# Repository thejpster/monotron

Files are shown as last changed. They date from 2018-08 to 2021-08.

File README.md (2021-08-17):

# Monotron.

> A simple 1980's home computer style application for the Tiva-C Launchpad

## The Monotron is no more

Monotron was fun, but it was only ever a tech demo rather than something we could build on. Check out <https://github.com/neotron-compute/> for our new family of ARM-based, Rust-powered home computers. 

## Introduction

Monotron is powered by a Texas Instruments TM4C123 microcontroller, containing
an ARM Cortex-M4 core and a number of peripherals. This processor was chosen
because it is available on an inexpensive dev-kit - the Tiva-C Launchpad - and
I happened to have some lying around. The challenge I set myself was, how much
can you squeeze out of this tiny CPU? And can you do it all in pure-Rust?

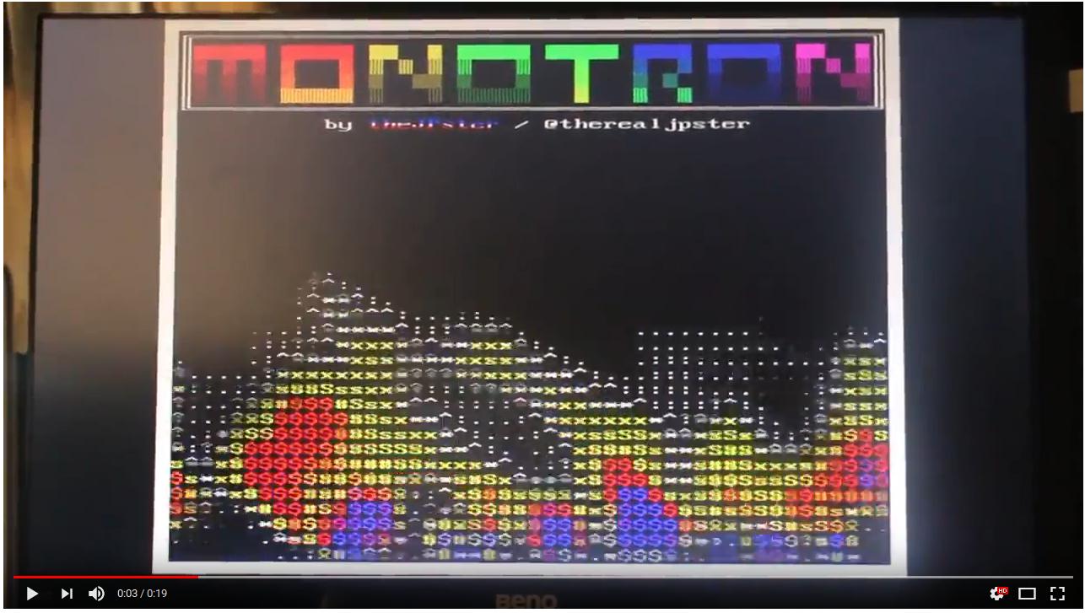
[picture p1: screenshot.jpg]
YouTube screenshot of a video of Monotron Monotron on Youtube

[See Monotron in Action!](https://www.youtube.com/watch?v=7x_92PXKSN4)

## The Future

Monotron has been replaced by the [Neotron 32](https://github.com/neotron-compute/Neotron-32-Hardware), part of the [Neotron family](https://neotron-compute.github.io). All future work will happen under the Neotron banner, and this repo is in archive mode.

## Features

* 800x600 8-colour VGA output
* 32 KiB SRAM (24 KiB usable for applications)
* 256 KiB Flash ROM
* Choice of low-memory 48x36 text display mode or full 384x288 bitmap graphics mode
* 8-bit mono audio output with 3 channel, 4 waveform synthesiser
* USB Serial I/O
* Atari 9-pin joystick interface
* Simple command-line interface
* I2C expansion interface
* Loadable apps
* Battery backed real-time clock*
* 25-pin IBM PC style parallel printer port*
* MIDI In, Out and Through*
* PS/2 Keyboard and Mouse*
* RS-232 Serial port*
* Watch this space!

 _* Requires additional hardware, included on the [Monotron PCB](#monotron-pcb)_

## Video

Monotron generates an 800x600 VGA video signal at 60 Hz using three SPI
peripherals and a timer to generate the horizontal sync signals. It can do
this because the VGA signal has a pixel clock of 40 MHz and the Tiva-C
Launchpad's TM4C123 CPU runs at 80 MHz. We save on the number of pixels we
have to push through the SPIs by running at half-resolution horizontally
(giving 400x600), which also halves the pixel clock to 20 MHz. I did try 40
MHz mode and it didn't work.

Monotron has two 'modes' it can display on this VGA output.

### Text Mode

Text Mode has a 48 character by 36 line display. Each character cell is 8
pixels wide and 16 pixels high and can take any character from the 8-bit [MS-
DOS Code Page 850](https://en.wikipedia.org/wiki/Code_page_850) character set,
and can have any foreground and background colour from the supported set:

* White
* Red
* Yellow
* Green
* Cyan
* Blue
* Magenta
* Black

The text buffer takes up `48 x 36 x 2 = 3,456` bytes of SRAM.

The built-in font is taken from
[FreeBSD](http://web.mit.edu/freebsd/head/share/syscons/fonts/cp850-8x16.fnt).
There's also a second font which implements Teletext block graphics (or
'sixels').

Any line of text can be displayed in "double height" mode, showing either the
top-half or bottom-half.

Finally, the display is framed with an 8 pixel border at the sides and a 12
pixel border at the top and bottom, to make everything fit neatly and to help
with any minor overscan issues if you use an actual CRT monitor.

### Graphics Mode

Graphics Mode can be enabled and disabled at run-time. It's not enabled by
default because bitmap graphics take up a lot of RAM!

You can attach a 1-bit-per-pixel graphics buffer that is some multiple of 384
pixels (i.e. 384 bits or 48 bytes) long. This buffer is displayed using line-
doubling (i.e. every line is shown twice) so you can go up to 384x288
resolution maximum, which will fill the screen. Each bit from the bitmap is
coloured according to the text cell (see above) it sits on top of, much like a
ZX Spectrum. A full-screen bitmap therefore uses the 3,456 bytes of SRAM from
text-mode plus an additional `384x288 / 8 = 13,824` bytes of SRAM.

## Compiling

You will need to build using Rust Nightly, as we need various experimental
features for Embedded development that are not yet available in Stable.

```
$ rustup toolchain install nightly
$ git clone https://github.com/thejpster/monotron.git
$ cd monotron
$ rustup override set nightly
$ rustup target add thumbv7em-none-eabihf
$ cargo build --release
```

To program the board, you can use lm4flash:

```
$ cargo build --release
$ arm-none-eabi-objcopy -O binary ./target/thumbv7em-none-eabihf/release/monotron ./target/thumbv7em-none-eabihf/release/monotron.bin
$ lm4flash ./target/thumbv7em-none-eabihf/release/monotron.bin
```

Or you can debug in GDB (which will automatically load the program first):

```
$ openocd
<switch to a different terminal>
$ cargo run --release
```

OpenOCD should read our `openocd.cfg` file, which directs it to use the
correct configuration. You may need to run `sudo openocd` if your user doesn't
have permission to open the USB device.

To exit GDB, you may need to press Ctrl-C multiple
times, as it seems it can get a bit stuck.

## Connecting

You have two options when running a Monotron.

1. You can take a bare Tiva-C Launchpad and wire up various connectors using
   the pin-outs in the following sections.
2. You can skip all that make yourself a [Monotron PCB](#monotron-pcb)!

### VGA

Your VGA connector requires five wires:

* Pin 1: Red - connect to PF1 via a 330 Ohm resistor.
* Pin 2: Green - connect to PB7 via a 330 Ohm resistor.
* Pin 3: Blue - connect to PD3 via a 330 Ohm resistor.
* Pin 5: Ground - connect to GND
* Pin 6: Red Return - connect to GND
* Pin 7: Green Return - connect to GND
* Pin 8: Blue Return - connect to GND
* Pin 13: H-Sync - connect to PB4
* Pin 14: V-Sync - connect to PB5

I'm using this arrangement using random resistors I found on my desk, and it
works for me (although the picture is a bit dim, as it actually produces about
0.6V peak rather than 0.7V):

```
-----+
     |     +------+ 330 Ohm        Co-ax in the VGA cable
PB7 o+-----|      |------------(o)==================)+
     |     +------+                                  |
-----+                                               |
                                                    +-+
                                                    | |
                                                    | | 75 Ohm
                                                    | | (in Monitor)
                                                    +-+
                                                     |
                                                     o
                                                    GND
```

The 330 Ohm resistor forms a resistive divider with the 75 Ohm resistor in the
monitor. This is needed to drop the 3.3V output down to 0.7V. Some monitors
are more tolerant of over voltage than others. The higher the resistor you
use, the less current you pulling out of the GPIO pin (we're just over 8mA
currently, which is a bit high) but the lower the voltage the monitor will see
and the dimmer your picture will be. Conversely if you lower the resistor,
more current will flow but it'll be a brigher picture. I'd save your chip from
damage and just wind the brightness control up!

Obviously only one channel is shown above - wire up the blue and red channels
in exactly the same fashion. Finally, don't forget to keep your wires short!
You will have noise if you try and send a 20 MHz signal down 10cm of
unshielded wire.

In a perfect world, your board would offer a 75 ohm source impendance matching
the monitor's 75 ohm impedance, to reduce reflections, but at this resolution
it doesn't seem to matter. If you want do do that, you'll need to make a
resistive divider to drop the 3.3V to 1.4V, and then feed that through a
high-bandwidth (>20 MHz) unity-gain amplifier, with a 75 ohm resistor on the
output. The pair of 75 ohm resistors will then drop the 1.4V to 0.7V in the
monitor.

### UART

Monotron primarily uses UART0, which is converted to USB Serial by the
on-board companion chip on the Tiva-C Launchpad. Connect with your favourite
Serial terminal at 115,200bps, then send UTF-8 characters and they'll get
converted to virtual keyboard input, allowing you to drive the Monotron.

There's also a second UART (UART1), which has RTS/CTS hardware handshaking
lines connected (but not DSR, DTR or RI). On the Monotron PCB these are
brought out to pin header J8. By fitting six jumpers on this header, the
on-board MAX3232 level shifter is activated, driving RS-232 signals on the
DE9M connector, J12. This connector is wired as [Data Terminal
Equipment](https://en.wikipedia.org/wiki/Data_terminal_equipment) or _DTE_ (as
opposed to [Data Communications
Equipment](https://en.wikipedia.org/wiki/Data_circuit-terminating_equipment)
or _DCE_). This means that Monotron transmits data on DE9 pin 3, and it's
designed to connect to Serial AT modems or other peripherals. Other computers
(like an old IBM PC) and even USB to RS-232 adaptors are most likely wired DTE
and so to connect one to the Monotron you'll most likely need a [null-modem
cable](https://en.wikipedia.org/wiki/Null_modem) (one that swaps pins 3 + 4
and pins 7 + 8).

Bonus points to the first person to write a BBS program for Monotron that lets
you dial up on a 56k modem.

Extra bonus points to the first person to write an xmodem file transfer
program so you can transfer files from SD card over RS-232 to an xmodem
utility on your old MS-DOS 3.3 IBM PC.

_Note: The Joystick connector looks the same as the RS232 connector - don't
mix them up!_

On the Monotron PCB, a third UART (UART3) is routed through various
opto-isolators to the MIDI In and MIDI Out ports. The MIDI Through port just
repeats everything received on the MIDI In port.

Finally, also on the Monotron PCB, a fourth UART (UART7) connects to a 5V
AtMega48 which is used as an I/O expander. This microcontroller drives two
PS/2 ports (one for keyboard, one for the mouse) as well as a full IBM
PC-style 25-pin parallel printer port.

| Launchpad Pin | Tiva-C Pin | External Pin | Function (from Monotron's point of view) |
|---|---|---|---|
| N/A | PA0 | N/A | USB Serial Rx |
| N/A | PA1 | N/A | USB Serial Tx |
| J4.8 | PD6 | J12 pin 3 | RS-232 Tx |
| J4.9 | PD7 | J12 pin 2 | RS-232 Rx |
| J4.10 | PF4 | J12 pin 7 | RS-232 RTS |
| J3.2 | GND | J12 pin 8 | RS-232 CTS |
| J4.6 | PC6 | J11 pin 4/5  | MIDI In |
| J4.7 | PC7 | J9 pin 4/5 | MIDI Out |
| N/A | N/A | J10 pin 4/5  | MIDI Through  |

### Audio

Monotron can generate 8-bit audio output using PWM on pin PE4. I use the
[monotron- synth](https://github.com/thejpster/monotron-synth) which has a
three-channel wavetable synthesiser which can bleep and bloop with square
waves, sine waves, sawtooth waves and generate white noise.

You'll need to run the pin through a low-pass filter to remove the noise, and
connect it to an amplifier as the GPIO pin won't really supply much current.

| Launchpad Pin | Tiva-C Pin | TRS | Function  |
|---|---|---|---|
| J1.5 | PE4 | Ring/Tip |Audio Left |
| J1.6 | PE5 | Tip |Audio Right|
| J3.2 | GND | Sleeve |Common |

Currently audio only comes out as Mono on PE4 (Left). If this is a problem for
your amplifier, setting jumper J1 on the PCB to 1-2 allows you to route Audio
Left to Sleeve as well as Tip. Setting J1 to 2-3 enables stereo support,
should that ever get developed.

### Joystick

There are five active-low inputs corresponding to Up, Down, Left, Right and
Fire. You can connect these inputs to a standard Atari or Commodore 9-pin
Joystick as follows:

| Launchpad Pin | Tiva-C Pin | Joystick Pin | Function |
|---|---|---|---|
| J3.8 | PE2 | 1 | Up |
| J3.9 | PE3 | 2 | Down |
| J4.8 | PD6 | 3 | Left |
| J4.9 | PD7 | 4 | Right |
| J4.10 | PF4 | 6 | Fire |
| J3.2 | GND | 8 | Ground |

A Sega Master System (tm) controller should work, except you'll only be able
to use Button 1 not Button 2. A Sega Mega Drive (tm) controller probably won't
work because it has more buttons than there are pins, and so uses a 5V powered
multiplexer to select between the two banks of buttons. 15-pin Analog PC
joysticks won't work either.

### SD Card

You can load programs and data from an SD card, from the first Primary MBR
(standard old-style MS-DOS) partition, formatted as either FAT16 or FAT32. Use
a standard SD Card SPI breakout adaptor, connected up as follows:

| Launchpad Pin | Tiva-C Pin | Function |
|---|---|---|
| J2.10 | PA2 | Clock |
| J2.9 | PA3 | Chip Select  |
| J2.8 | PA4 | MISO/Data Out|
| J1.8 | PA5 | MOSI/Data In |

SD cards operate at 3.3v so no level shifters are required, but many cards
will require a 47k (well, between 10k and 100k) pull-up to 3.3v on all four
data pins. If you don't use these pull-ups, the pins float while the Monotron
is booting, and these fluctuations may upset the SD card, giving you random
timeouts and other spurious effects. Some cards tolerate this better than
others, so YMMV. If in doubt, just add the pull-ups (they're missing on rev
0.7.0 of the PCB, but will be on 0.8.0+).

On the console you use the `mount` command to scan the disk, then `dir` to
show the root directory contents. You can also `dload`, `ddump` and `dpage`
commands to load, hex-dump and print files to the screen. A program loaded
with `dload` can subsequently be executed with the `run` command.

### I2C

The [Monotron PCB](#monotron-pcb) has an I2C expansion header connected to
`I2C1`. The PCB can also optionally be fitted with an [Microchip
MCP7940N](https://www.microchip.com/wwwproducts/en/MCP7940N) battery-backed
real time clock chip. Driver support for this chip is TBC.

The PCB pulls-up the I2C bus to 5V through 4.7k pull-ups. On these particular
pins the TM4C123 happens to be 5V tolerant and so it simply runs the I2C pins
in open-drain mode without a level shifter.

| Launchpad Pin | Tiva-C Pin | External Pin | Function |
|---|---|---|---|
| J2.1 | GND | J6 pin 1 | Ground |
| J3.1 | 5V | J6 pin 2 | 5V Power |
| J1.10 | PA7 | J6 pin 3 | SDA |
| J1.9 | PA6 | J6 pin 4 | SCL |

### PS/2 Keyboard

The initial PS/2 keyboard support sort of worked, but it wasn't reliable I so
took it out again. The fundamental problem was that it's really hard to sample
a 10 to 15 kHz incoming synchronous signal without using SPI slave peripheral
(they're all in use) and while bit-bashing timing-critical video signals at 20
MHz. Either you drop random key events (leading to missing characters or stuck
keys), or the video wobbles every time a key is pressed (like a ZX81). Neither
was ideal.

On the [Monotron PCB](#monotron-pcb) I work around this issue by adding an
Atmel AtMega48 microcontroller as an I/O expander, connected to [UART](#uart)
7. Look in the [`avr_kb`](./avr_kb) folder for more information.

__Note:__ There's a bug in the 0.7.0 PCB where both PS/2 connector pinouts are
mirror image, compared to how they should be. It happened because although the
connector drawings said "Bottom View" quite clearly, I didn't pay enough
attention and assumed they were viewed from above! To use the PS/2 connectors,
they must be fitted to the underside of the PCB (i.e. opposite to all the
other connectors). This will be fixed in the next PCB revision.

### MIDI

The [Monotron PCB](#monotron-pcb) has three 5-pin DIN MIDI ports: In, Out and
Through. These are connected to UART 3.

### Parallel Printer Port

The 25-pin Parallel Printer Port is connected to the Monotron PCB's AtMega48
I/O controller. You send commands to the AtMega to get it to drive the printer
port. Currently only SPP (classic mono-directional support as found on the
original IBM PC) is planned for support. Support for the fancier EPP and ECP
modes is TBD.

## Monotron PCB

There's now a PCB! It features:

* 2x20 pin headers, to mate with the TM4C123 Launchpad (other Launchpads like
  the TM4C129 and MSP430 have not been tested and almost certainly won't work)
* 5V power jack (2.1mm barrel jack, centre +ve)
* [VGA](#vga) port (DE15HD female)
* Atari/Commodore [joystick](#joystick) port (DE9 male)
* [Micro-SD Card](#sd-card) slot
* [3.5mm stereo line out](#audio)
* [RS-232](#uart) port (DE9 male)
* 2.54mm (100 mil) jumpers to disconnect the RS232 driver and allow you to
  connect a 3.3v FTDI type TTL serial cable instead.
* [MIDI](#midi) In, Out and Through ports, with opto-isolation (5-pin DIN)
* 4-pin 2.54mm pitch (100 mil) [I2C](#i2c) expansion header (GND, 5V, SDA, SCL)
* Microchip MCP7940N I2C Real-Time Clock with battery back-up
* AtMega48 microcontroller, controlling:
  * IBM PC style parallel printer port (DB25 female)
  * PS/2 Keyboard port (6-pin mini-DIN)
  * PS/2 Mouse port (6-pin mini-DIN)

See the [pcb](./pcb) folder for Kicad files, Gerbers and PDF Schematics. If
you want to buy a PCB (with or without a kit of parts) send a message to
@therealjpster on Twitter, or via my Github e-mail. Rev 0.7.0 has some rough
edges, but I'm working on it.

## Running

When running, a simple command driven interface is presented. Commands can be
entered over serial, or using a PS/2 keyboard. Commands are split on
whitespace and then interpreted based on the left-most word. Enter the command
'help' to see a list of commands. Some commands place you in to a sub-menu -
use 'exit' to return to the previous menu.

## Loading apps

Applications can be compiled and loaded into RAM for exection. They must be
linked to run from address `0x2000_2000` and take less than 24 KiB for all
code and data combined. See the table below:

| Address | Length  | Description  |
|---|---|---|
| 0x0000_0000 | 256 KiB | OS Code |
| 0x2000_0000 | 8 KiB | OS Data |
| 0x2000_2000 | 24 KiB  | Application  |

The first four bytes of the image must be the address of the start function,
with prototype `fn start(const struct callbacks_t* callbacks) -> int32`. Apart
from that, applications are free to apportion the remaining 24,572 bytes as
they see fit.

*Note:* The application does not need to provide a stack region - the Monotron
ROM will handle that using the system stack.

The callback structure supplied to the application's entry function is defined
in `api.rs`, but in C looks like:

```C
struct callbacks_t {
    int32_t (*putchar)(void* p_context, char ch);
    int32_t (*puts)(void* p_context, const char*);
    int32_t (*readc)(void* p_context);
    void (*wfvbi)(void* p_context);
    int32_t (*kbhit)(void* p_context);
    void (*move_cursor)(void* p_context, unsigned char row, unsigned char col);
    int32_t (*play)(void* p_context, uint32_t frequency, uint8_t channel, uint8_t waveform, uint8_t volume);
    void (*change_font)(void* p_context, uint32_t mode, const void* p_font);
    uint8_t (*get_joystick)(void* p_context);
    void (*set_cursor_visible)(void* p_context, uint8_t visible);
};
```

The C functions exported to the apps are:

* `puts` - print an 8-bit string (certain escape sequences are understood).
  Note that unlike the C routine of the same name, this function does not
  append a newline automatically. It is more like `fputs(s, stdout)`.
* `putchar` - print an 8-bit character
* `readc` - blocking wait for keyboard/serial input
* `wfvbi` - Wait For next Vertical Blanking Interval
* `kbhit` - return 1 if a key has been pressed (and so `readc` won't block),
  else return 0
* `move_cursor` - move the cursor to change where the next print goes
* `play` - play a note on one of the synthesizer channels
* `change_font` - changes the font used on screen to the normal CodePage 850,
  the Teletext font, or a custom font supplied by the application.
* `get_joystick` - returns the current state of the joystick input. Bits 0-4
  correspond to Fire, Right, Left, Down and Up respectively.
* `set_cursor_visible` - Pass 0 to disable the `_` cursor, or non-zero to enable it.

You can use the `upload` Python script in this repo to upload binary images
into RAM, or you can use the `dload` to load them from SD card.

See [monotron-apps](https://github.com/thejpster/monotron-apps) for example
apps which will run from Monotron's RAM, along with a wrapper which makes
using the callbacks as simple as using a normal C library.

## Unreleased changes (will be 0.10.0)

* Fixed video interrupt jitter by entering WFI before drawing pixels.
* Updated VGA framebuffer callback API

## Changelog

* Version 0.9.2 - Updated menu interface crate
* Version 0.9.0 - Added I2C commands and support for the AtMega keyboard
  controller (WIP) on the Monotron PCB.
* Version 0.8.0 - Added cursor support to ABI. Added basic SD Card support
  (read-only).
* Version 0.7.0 - Move application RAM to 0x2000_2000. Added cursor support.
  Moved callback pointer.
* Version 0.6.3 - Fixed Joystick support.
* Version 0.6.2 - Add Joystick support.
* Version 0.6.1 - Add Teletext font and support for font-switching in apps.
* Version 0.6.0 - Added sound and support for apps running from RAM. Removed
  PS/2 keyboard support.
* Version 0.5.0 - Added 1bpp graphics mode.
* Version 0.4.0 - Added PS/2 keyboard support.
* Version 0.3.0 - Backspace works.
* Version 0.2.0 - Switch to a text buffer to save RAM. Basic animations work.
* Version 0.1.0 - First release. VGA output works but menu is full of dummy
  commands and there's no keyboard input.

## License

Licensed under either of

- Apache License, Version 2.0 ([LICENSE-APACHE](LICENSE-APACHE) or
  http://www.apache.org/licenses/LICENSE-2.0)

- MIT license ([LICENSE-MIT](LICENSE-MIT) or http://opensource.org/licenses/MIT)

at your option.

## Contribution

Unless you explicitly state otherwise, any contribution intentionally
submitted for inclusion in the work by you, as defined in the Apache-2.0
license, shall be dual licensed as above, without any additional terms or
conditions.

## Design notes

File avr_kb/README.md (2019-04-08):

# Monotron I/O Controller

## Introduction

This is the firmware for the Monotron's I/O controller. It is an Atmel AVR
Atmega48, and it controls the:

* PS/2 Keyboard port
* PS/2 Mouse port
* PC Printer (aka LPT, or Centronics) port

It talks to the main Monotron MCU over a serial link at 115,200 bps (8-data
bits, no parity, 1 stop bit).

NB: As an interim test, there's an Arduino sketch in the `keyboard` folder
which just emits raw scan-codes over the UART at 19,200 baud.

## Compilation

This firmware builds with `avr-gcc` and `meson`.

```shell
$ meson --cross-file=./avr-cross.txt ./build
$ cd ./build
$ ninja # Builds a debug ELF and .hex file
$ ninja size # Tells you how big it is
```

## Pinout

| Port   | Pin |  Direction     | Name          | Routed to  | Description              |
|--------|-----|----------------|------------- -|------------|--------------------------|
| B      | 0   | Output         | LPT_D0        | J13 pin 2  | LPT Output bit 0         |
| B      | 1   | Output         | LPT_D1        | J13 pin 3  | LPT Output bit 1         |
| B      | 2   | Output         | LPT_D2        | J13 pin 4  | LPT Output bit 2         |
| B      | 3   | Output         | LPT_D3        | J13 pin 5  | LPT Output bit 3         |
| B      | 4   | Output         | LPT_D4        | J13 pin 6  | LPT Output bit 4         |
| B      | 5   | Output         | LPT_D5        | J13 pin 7  | LPT Output bit 5         |
| B      | 6   | Output         | LPT_D6        | J13 pin 8  | LPT Output bit 6         |
| B      | 7   | Output         | LPT_D7        | J13 pin 9  | LPT Output bit 7         |
| C      | 0   | I/O Open-drain | KB_CLK        | J14 pin 5  | PS/2 Keyboard clock      |
| C      | 1   | I/O Open-drain | MS_CLK        | J15 pin 5  | PS/2 Mouse clock         |
| C      | 2   | I/O Open-drain | KB_DATA       | J14 pin 1  | PS/2 Keyboard data       |
| C      | 3   | I/O Open-drain | MS_DATA       | J15 pin 1  | PS/2 Mouse data          |
| C      | 4   | Output         | LPT_nINIT     | J13 pin 16 | Initialise Printer       |
| C      | 5   | Input          | LPT_SEL       | J13 pin 13 | Select (from printer)    |
| C      | 6   | Output         | LPT_nSELPRIN  | J13 pin 17 | Select (to printer)      |
| D      | 0   | Input          | UART_RX       | U1 PE1     | UART receive from MCU    |
| D      | 1   | Output         | UART_TX       | U1 PE0     | UART transmit to MCU     |
| D      | 2   | Input          | LPT_nACK      | J13 pin 10 | Acknowledge from Printer |
| D      | 3   | Input          | LPT_BUSY      | J13 pin 11 | Printer is Busy          |
| D      | 4   | Input          | LPT_nPE       | J13 pin 12 | Printer found Paper End  |
| D      | 5   | Input          | LPT_nERROR    | J13 pin 15 | Printer Error            |
| D      | 6   | Output         | LPT_nAUTOFEED | J13 pin 14 | Enable Auto Feed         |
| D      | 7   | Output         | LPT_nSTROBE   | J13 pin 1  | Latch data               |

Refer to [the schematic](../pcb/schematic.pdf) for more details.

## Protocol

The protocol between the I/O controller and the main MCU is pretty simple. As
the MCU is pretty busy drawing the screen, and there's only a 16-byte UART
FIFO on the MCU, we keep the I/O controller mostly quiet until commanded to
send a packet of data. This will normally occur once per screen refesh (so, 60
Hz), which should be plenty for reading the keyboard and mouse.

### Requests

These are the messages the MCU can send to the I/O controller. All are 1 byte
long, but some have following bytes.

* RESET_REQ (0x41) - Resets the attached keyboard and mouse as well as all
  status information.
* PS2_DATA_REQ (0x42) - Requests all the keypresses and mouse movements since the
  last call.
* PS2_LED_REQ (0x43) <byte> - Set the keyboard LEDs
* LPT_DATA_REQ (0x44) <byte> - Write a byte to the 8-bit LPT port. If you are
  talking to a printer you have to pulse nSTROBE and poll the ACK signal
  manually. If you are using the port as GPIO then you can do what you like.
* LPT_READ_REQ (0x45) - Read the status bits
* LPT_CTRL_REQ (0x46) <byte> - Set the control bits:
    * Bit 0: nSTROBE
    * Bit 1: nAUTOFEED
    * Bit 2: nSELECT
    * Bit 3: INIT
* LPT_BUFFERED_DATA_REQ (0x47) <len> <bytes...> - Write a a number of bytes to
  a buffer. Each will be automatically clocked out with a pulse of the nSTROBE
  line, then waiting for the printer to raise and then lower the BUSY signal.
* LPT_READ_PEND_REQ (0x48) <mask> <levels> - Send an indication when the pins specified by
  <mask> have the levels specified by <levels>. Use 0x00 and 0x00 to cancel an existing pend.
* LPT_SET_MODE_REQ (0x49) <mode> - Try and configure a specific IEEE-1284 mode.
    * 0x00 - Compatibility mode
    * Other values reserved
* PING_REQ (0x4A) - Empty request
* BOOTLOADER_REQ (0x4B) - Go to firmware programming mode

### Confirmations

These are the messages the I/O controller will send to the MCU, in response to the requests.

* RESET_CFM (0x61) - Confirms the reset is in progress. A BOOTED_IND will be
  sent when the reset is complete.
* PS2_DATA_CFM (0x62) <kb0> <kb1> <kb2> <mouse status> <mouse X> <mouse Y> - Keyboard and
  mouse data received since last previous PS2_DATA_CFM sent.
* PS2_LED_CFM (0x63) - Confirm the keyboard LEDs have been set
* LPT_DATA_CFM (0x64) - Sent when a byte has been written to the printer.
* LPT_READ_CFM (0x65) <byte> - Returns the status bits:
    * Bit 0: nACK
    * Bit 1: BUSY
    * Bit 2: OUT_OF_PAPER
    * Bit 3: SELECT
    * Bit 4: nERROR
* LPT_CTRL_CFM (0x66) - Sent when the control bytes have been written.
* LPT_BUFFERED_DATA_CFM <status> (0x67) - If status=0, buffered data has been
  stored, else there was an error (e.g. too much data).
* LPT_READ_PEND_CFM (0x68) - A pend has been received.
* LPT_SET_MODE_CFM (0x69) <result> - Result of a mode configuration.
    * 0x00 - Mode successfully negotiated
    * Non-zero - An error occurred
* PING_CFM (0x6A) - Empty response
* BOOTLOADER_CFM (0x6B) - Entering firmware programming mode

### Indications

These messages can be sent asynchronously by the I/O controller to the MCU.

* BOOTED_IND (0x30) <status> - Confirms the I/O controller is running and
  gives the keyboard and mouse status.
    * Bit 0 - 1 = Keyboard present, 0 = Keyboard missing
    * Bit 1 - 1 = Mouse present, 0 = Mouse missing
    * Bit 2:5 - 4-bit firmware version (v0..v15)
    * Bit 6 - Reserved (MCU should ignore)
    * Bit 7 - Always 1
* PS2_DATA_IND (0x31) - Indicates that data is waiting to be read. Only sent
  once, until a PS2_DATA_REQ is seen.
* LPT_BUFFER_EMPTY_IND (0x32) - Indicates that the LPT buffer is now empty and
  more bytes can be sent.
* LPT_READ_PEND_IND (0x33) <pins> - The input pins matched the given levels.
* BAD_COMMAND_IND (0x34) - Send when a bad request is received. That request
  will not receive a Confirmation.

### Keyboard Data Format

The PS/2 Scan Code Set 2 is translated by the I/O controller into a basic code
where each key is numbered 0..127. The top bit is then set for a key-up event
and cleared for a key-down event. The 00 byte is a no-op. Only three key
events can be sent every frame (i.e. at 60 Hz, or 180 key events per second or
90 keystrokes per second). I doubt anyone will need to type that fast on a
Monotron.

* F9: 0x01
* AltRight: 0x02
* F5: 0x03
* F3: 0x04
* F1: 0x05
* F2: 0x06
* F12: 0x07
* ControlRight: 0x08
* F10: 0x09
* F8: 0x0A
* F6: 0x0B
* F4: 0x0C
* Tab: 0x0D
* BackTick: 0x0E
* WindowsLeft: 0x0F
* WindowsRight: 0x10
* AltLeft: 0x11
* ShiftLeft: 0x12
* Menus: 0x13
* ControlLeft: 0x14
* Q: 0x15
* Key1: 0x16
* NumpadSlash: 0x17
* NumpadEnter: 0x18
* End: 0x19
* Z: 0x1A
* S: 0x1B
* A: 0x1C
* W: 0x1D
* Key2: 0x1E
* ArrowLeft: 0x1F
* Home: 0x20
* C: 0x21
* X: 0x22
* D: 0x23
* E: 0x24
* Key4: 0x25
* Key3: 0x26
* Insert: 0x27
* Delete: 0x28
* Spacebar: 0x29
* V: 0x2A
* F: 0x2B
* T: 0x2C
* R: 0x2D
* Key5: 0x2E
* ArrowDown: 0x2F
* ArrowRight: 0x30
* N: 0x31
* B: 0x32
* H: 0x33
* G: 0x34
* Y: 0x35
* Key6: 0x36
* ArrowUp: 0x37
* PageDown: 0x38
* PageUp: 0x39
* M: 0x3A
* J: 0x3B
* U: 0x3C
* Key7: 0x3D
* Key8: 0x3E
* Comma: 0x41
* K: 0x42
* I: 0x43
* O: 0x44
* Key0: 0x45
* Key9: 0x46
* Fullstop: 0x49
* Slash: 0x4A
* L: 0x4B
* SemiColon: 0x4C
* P: 0x4D
* Minus: 0x4E
* Quote: 0x52
* BracketSquareLeft: 0x54
* Equals: 0x55
* CapsLock: 0x58
* ShiftRight: 0x59
* Enter: 0x5A
* BracketSquareRight: 0x5B
* BackSlash: 0x5D
* Backspace: 0x66
* Numpad1: 0x69
* Numpad4: 0x6B
* Numpad7: 0x6C
* Numpad0: 0x70
* NumpadPeriod: 0x71
* Numpad2: 0x72
* Numpad5: 0x73
* Numpad6: 0x74
* Numpad8: 0x75
* Escape: 0x76
* NumpadLock: 0x77
* F11: 0x78
* NumpadPlus: 0x79
* Numpad3: 0x7A
* NumpadMinus: 0x7B
* NumpadStar: 0x7C
* Numpad9: 0x7D
* ScrollLock: 0x7E
* F7: 0x7F

### Mouse Data Format

This is as per the PS/2 specification, except that mutiple mouse packets (sent at 100 Hz) may be coalesced into a single message to the MCU (which only reads data at 60 Hz or less).

* Status:
    * Bit 7 - Y overflow
    * Bit 6 - X overflow
    * Bit 5 - Y sign bit
    * Bit 4 - X sign bit
    * Bit 3 - Always 1
    * Bit 2 - Middle Button
    * Bit 1 - Right Button
    * Bit 0 - Left Button
* X: Distance moved in the X direction since the last reading, in the range 0..255 (plus the sign bit above, so -255 to +255)
* Y: Distance moved in the Y direction since the last reading. Values are per `X` above.

## Licence

The code is Copyright (c) Jonathan 'theJPster' Pallant 2019. It is available under the Apache 2.0 or MIT licences, at your option.

The code in the `third_party/avr_uart` folder is under the following licence:

```
Copyright (C) 2012 Andy Gock

This program is free software; you can redistribute it and/or modify
it under the terms of the GNU General Public License as published by
the Free Software Foundation; either version 2 of the License, or
any later version.

This program is distributed in the hope that it will be useful,
but WITHOUT ANY WARRANTY; without even the implied warranty of
MERCHANTABILITY or FITNESS FOR A PARTICULAR PURPOSE.  See the
GNU General Public License for more details.
```

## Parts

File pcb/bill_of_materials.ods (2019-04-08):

Monotron BOM
Rev 0.8.0
Copyright (c) Jonathan ‘theJPster’ Pallant 2019 CC-BY-SA 4.0
Part | Qty | Type | Manufacturer | Manuf. Part No | Supplier A | Supplier A Part No | Price Ea | Line Total
C6 C7 C11 C12 C13 C14 C17 | 7 | Capacitor 100nF | TDK | FG18X7R1H104KNT06 | Digikey | 445-173265-1-ND | £0.20 | £1.40
C1 C2 | 2 | Capacitor 10uF | Panasonic | ECA-1VM100 | Digikey | P5161-ND‎ | £0.14 | £0.28
C15 C16 | 2 | Capacitor 12pF | TDK | FG18C0G1H120JNT06 | Digikey | 445-173173-1-ND | £0.18 | £0.36
C4 C5 | 2 | Capacitor 33nF | TDK | FG18X7R1H333KNT06 | Digikey | 445-173272-1-ND | £0.20 | £0.40
C8 C9 C10 | 3 | Capacitor 470nF | TDK | FG18X7R1H474KRT00 | Digikey | 445-181252-ND | £0.24 | £0.72
C3 | 1 | Capacitor 47uF | Panasonic | ECA-1VM470 | Digikey | P5164-ND | £0.16 | £0.16
BT1 | 1 | Coin Cell Holder | Keystone | 103 | Digikey | 36-103-ND | £0.18 | £0.18
Y1 | 1 | Crystal 32768 Hz 6pF | Citizen Finedevice | CFS-20632768DZBB | Digikey | 300-8301-ND | £0.18 | £0.18
J13 | 1 | D-Type DB25F | Amphenol ICC (FCI) | ID25S33E4GV00LF | Mouser | 649-ID25S33E4GV00LF | £1.21 | £1.21
J7 | 1 | D-Type DE15HDF | Amphenol ICC (FCI) | ID15S33E4GV00LF | Digikey | 609-5371-ND | £0.92 | £0.92
J5 J12 | 2 | D-Type DE9M | Amphenol ICC (FCI) | ID09P33E4GV00LF | Digikey | 609-5918-ND | £0.81 | £1.62
J2 | 1 | DC Jack 2.1mm / 5.5mm | CUI | PJ-102A | Digikey | CP-102A-ND | £0.49 | £0.49
J9 J10 J11 | 5 | DIN 5pin 180 degree | RS Pro | YE-138X | RS | 491-087 (5 pack) | £0.36 | £1.79
J14 J15 | 2 | DIN mini 6-pin | TE | 5749180-1 | Digikey | 5749180-1-ND | £1.37 | £2.74
D1 | 1 | Diode 1N4148 | On Semi | 1N4148 | Digikey | 1N4148FS-ND | £0.08 | £0.08
J1 | 1 | Header 1x3 | Sullins | PRPC003SAAN-RC | Digikey | S1011EC-03-ND | £0.09 | £0.09
J6 | 1 | Header 1x4 | Sullins | PRPC004SAAN-RC | Digikey | S1011EC-04-ND | £0.11 | £0.11
U1A U1B | 2 | Header 2x10 | Sullins | PRPC010DAAN-RC | Digikey | S2011EC-10-ND | £0.38 | £0.76
J17 | 1 | Header 2x3 | Sullins | PRPC003DAAN-RC | Digikey | S2011EC-03-ND | £0.14 | £0.14
J8 | 1 | Header 2x6 | Sullins | PRPC006DAAN-RC | Digikey | S2011EC-06-ND | £0.26 | £0.26
U4 | 1 | IC 6N138 | Lite-On | 6N138 | Digikey | 160-1795-ND | £0.62 | £0.62
U3 | 1 | IC 74LS14 | Texas Instruments | SN74LS14N | Digikey | 296-1643-5-ND | £0.51 | £0.51
U5 | 1 | IC AtMega328 | Atmel | ATMEGA328-PU | Digikey | ATMEGA328-PU-ND | £1.49 | £1.49
U2 | 1 | IC MAX3232 | Renesas | ICL3232CPZ | Digikey | ICL3232CPZ-ND | £1.32 | £1.32
U6 | 1 | IC MCP7940N-xP RTC | Microchip Technology | MCP7940N-I/P | Digikey | MCP7940N-I/P-ND | £0.62 | £0.62
J4 | 1 | Jack TRS 3.5mm | CUI | SJ1-3533NG | Digikey | CP1-3533NG-ND‎ | £0.89 | £0.89
D2 | 1 | LED Green 3mm | Wurth | 151031VS06000 | Digikey | 732-5008-ND | £0.12 | £0.12
U1 | 1 | Microcontroller Tiva Launchpad | Texas Instruments | EK-TM4C123GXL | Digikey | 296-35760-ND | £10.27 | £10.27
J3 | 0 | microSD Card Holder (in place of J16) | Sparkfun | BOB-00544 | Proto-Pic | PPBOB-00544 | £2.50 | £0.00
J16 | 1 | microSD Card Holder (in place of J3) | Hirose | DM3D-SF | Digikey | HR1941CT-ND | £1.33 | £1.33
R15 | 1 | Resistor 10K Ohm | Stackpole Electronics | RNMF14FTC10K0 | Digikey | S10KCACT-ND | £0.08 | £0.08
R1 R2 | 2 | Resistor 150 Ohm | Stackpole Electronics | RNMF14FTC150R | Digikey | S150CACT-ND | £0.08 | £0.16
R10 R11 R12 R13 R14 | 5 | Resistor 220 Ohm | Stackpole Electronics | RNMF14FTC220R | Digikey | S220CACT-ND | £0.08 | £0.40
R3 R4 | 2 | Resistor 270 Ohm | Stackpole Electronics | RNMF14FTC270R | Digikey | S270CACT-ND | £0.08 | £0.16
R7 R8 R9 | 3 | Resistor 330 Ohm | Stackpole Electronics | RNMF14FTC330R | Digikey | S330CACT-ND | £0.08 | £0.24
R5 R6 | 2 | Resistor 4.7k | Stackpole Electronics | RNMF14FTC4K70 | Digikey | S4.7KCACT-ND | £0.08 | £0.16
R16 R21 | 2 | Resistor 470 Ohm | Stackpole Electronics | RNMF14FTC470R | Digikey | S470CACT-ND | £0.08 | £0.16
U3A | 1 | Socket 14 pin | On Shore Technology | ED14DT | Digikey | ED3045-5-ND | £0.20 | £0.20
U2A | 1 | Socket 16 pin | On Shore Technology | ED16DT | Digikey | ED3046-5-ND | £0.14 | £0.14
U5A | 1 | Socket 28 pin | On Shore Technology | ED281DT | Digikey | ED3050-5-ND | £0.25 | £0.25
U4A U6A | 2 | Socket 8 pin | On Shore Technology | ED08DT | Digikey | ED3044-5-ND | £0.12 | £0.24
 |  |  |  |  |  |  | Total | £33.25
 |  |  |  |  |  |  | VAT | £6.65
 |  |  |  |  |  |  | Grand Total | £39.90

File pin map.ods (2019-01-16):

Monotron Pin Mapping
 |  | GPIO | On-Board | SPI | UART | Timer | I2C | Other | PWM | Notes
J1 | 1 | 3v3
J1 | 2 | PB5 |  | SSI2Fss |  | T1CCP1 |  |  | M0PWM3 | VGA V-Sync
J1 | 3 | PB0 |  |  | U1Rx | T2CCP0 |  |  |  | 4-wire UART In. Not 5V tolerant.
J1 | 4 | PB1 |  |  | U1Tx | T2CCP1 |  |  |  | 4-wire UART Out. Not 5V tolerant.
J1 | 5 | PE4 |  |  | U5Rx |  | I2C2SCL |  | M0PWM4 | Audio (Mono, or Left)
J1 | 6 | PE5 |  |  | U5Tx |  | I2C2SDA |  | M0PWM5 | Audio (Mono, or Right)
J1 | 7 | PB4 |  | SSI2Clk |  | T1CCP0 |  |  | M0PWM2 | VGA H-Sync
J1 | 8 | PA5 |  | SSI0Tx |  |  |  |  |  | SD/MMC MOSI
J1 | 9 | PA6 |  |  |  |  | I2C1SCL |  |  | I2C SCL
J1 | 10 | PA7 |  |  |  |  | I2C1SDA |  |  | I2C SDA
J2 | 1 | GND
J2 | 2 | PB2 |  |  |  | T3CCP0 | I2C0SCL |  |  | Spare GPIO 0
J2 | 3 | PE0 |  |  | U7Rx |  |  |  |  | UART from I/O Expander
J2 | 4 | PF0 | Button 0 |  | U1RTS | T0CCP0 |  | NMI |  | Spare GPIO 1 (open drain input only)
J2 | 5 | RESET
J2 | 6 | PB7 |  | SSI2Tx |  | T0CCP1 |  |  | M0PWM1 | Connected to J3.4 / VGA Blue
J2 | 7 | PB6 |  | SSI2Rx |  | T0CCP0 |  |  | M0PWM0 | Connected to J3.3 / Spare GPIO 2
J2 | 8 | PA4 |  | SSI0Rx |  |  |  |  |  | SD/MMC MISO
J2 | 9 | PA3 |  | SSI0Fss |  |  |  |  |  | SD/MMC CS / Disk Activity LED
J2 | 10 | PA2 |  | SSI0Clk |  |  |  |  |  | SD/MMC CLK
J3 | 1 | 5V0
J3 | 2 | GND
J3 | 3 | PD0 |  | SSI3/1Clk |  | W2TCCP0 | I2C3SCL |  | M0PWM6 | Connected to J2.7
J3 | 4 | PD1 |  | SSI3/1Fss |  | WT1CCP1 |  |  | M0PWM7 | Connected to J2.6
J3 | 5 | PD2 |  | SSI3/1Rx |  | WT3CCP0 | I2C3SDA |  | M0FAULT0 | Spare GPIO 3
J3 | 6 | PD3 |  | SSI3/1Tx |  | WT3CCP1 |  |  |  | VGA Green
J3 | 7 | PE1 |  |  | U7Tx |  |  |  |  | UART to I/O Expander
J3 | 8 | PE2 |  |  |  |  |  |  |  | JS Up
J3 | 9 | PE3 |  |  |  |  |  |  |  | JS Down
J3 | 10 | PF1 | Red LED | SSI1Tx | U1CTS | T0CCP1 |  |  |  | VGA Red
J4 | 1 | PF2 | Blue LED | SSI1Clk |  | T1CCP0 |  |  | M0FAULT0 | Unused (on-board LED)
J4 | 2 | PF3 | Green LED | SSI1Fss |  | T1CCP1 |  |  |  | Unused (on-board LED)
J4 | 3 | PB3 |  |  |  | T3CCP1 |  |  |  | Spare GPIO 4
J4 | 4 | PC4 |  |  | U4/1Rx/U1RTS | WT0CCP0 |  |  | M0PWM6 | 4-wire UART RTS
J4 | 5 | PC5 |  |  | U4/1Tx/U1CTS | WT0CCP1 |  |  | M0PWM7 | 4-wire UART CTS
J4 | 6 | PC6 |  |  | U3Rx | WT1CCP0 |  |  |  | MIDI In
J4 | 7 | PC7 |  |  | U3Tx | WT1CCP1 |  |  |  | MIDI Out
J4 | 8 | PD6 |  |  | U2Rx | WT5CCP0 |  |  |  | JS Left
J4 | 9 | PD7 |  |  | U2Tx | WT5CCP1 |  |  |  | JS Right
J4 | 10 | PF4 | Button 1 |  |  | T2CCP0 |  |  |  | JS Fire

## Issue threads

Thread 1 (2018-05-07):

Finish keyboard driver

thejpster, 2018-05-07:

thejpster, 2018-09-15:
Pull clock line low to belay keyboard output. Release during v-blank when we can process messages.

thejpster, 2018-09-22:
Or, pull clock line low just during scan-line setup period (which is a very high priority interrupt). We should be OK to process signals during the scan-line rendering if we're quick about it.

Interrupt latency is 12 cycles in and 10 cycles out. Plus a bit-banded GPIO pin read, a global variable write (the bit) and a global variable read/increment/write (the bit index). That's about 30 cycles, or 7.5 screen pixels. At 10 kHz we have to do that every 100us, so at most once every 4 scan lines (26.4us). At 16.7 kHz that's once every 60 us, or every other scan line.

Actually that's a thought - can we just poll the keyboard in the horizontal blanking interval?

thejpster, 2018-12-28:
V-blank isn't long enough. An 11 bit message at 10 kHz (minimum) is 1.1ms and the blanking interval is only ~790us.

* We could add a PDIP AtTiny to buffer the PS/2 scan codes for us, which we can then read out over I2C: https://www.mouser.co.uk/ProductDetail/Microchip-Technology-Atmel/ATTINY24A-PU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
* We could add a small ARM (harder to find 5V-tolerant and very hard to find in PDIP).
* We could add two 8-bit 74-series shift registers and an MCP23S17 I/O expander to read them in in parallel.

thejpster, 2019-08-25:
Used an external chip.

Closed 2019-08-25.

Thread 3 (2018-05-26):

Add a programming language

thejpster, 2018-05-26:
Ideally you would be able to write a game or other application on the Monotron, using the keyboard (or UART input) and without changing the contents of Flash. But what programming language?

* BASIC
* PicoC
* Lua
* MicroPython?
* Monkey
* Something else?

thejpster, 2018-07-20:
We don't really have the RAM to edit decent sized functions so we need a language we can tokenize / convert to byte code on a line-by-line basis, just like BASIC.

[Rhai](https://github.com/jonathandturner/rhai/tree/master/scripts) is an option, but the syntax might need a little tweaking to make it line based.

BBC Basic has some nice assembler support and plenty of examples.

We could also take BASIC and improve it a bit, with arrays and hashes, etc.

thejpster, 2018-09-15:
Ported TinyBasic.

thejpster, 2018-10-15:
Ported a 6502 emulator and Microsoft Enhanced BASIC.

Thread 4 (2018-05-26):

Add SWI

thejpster, 2018-05-26:
We need software interrupts so that applications can get the flash ROM to perform various things:

* Writing to the screen
* Reading from the keyboard
* Reading/writing the UART
* Waiting for the next vertical blanking interval
* Random numbers?
* malloc/free?

thejpster, 2018-09-16:
Done! Need to expand the API but can add issues for that.

Closed 2018-09-16.

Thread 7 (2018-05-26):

Load/Save

thejpster, 2018-05-26:
We need commands to load to RAM from the UART and save RAM to the UART. Maybe X-Modem? Y-Modem? Z-Modem? Kermit?

thejpster, 2018-09-27:
Have a raw load routine which reads in hex, but there's no checksums so sometimes you get corruption.

thejpster, 2018-10-06:
The hex load routine now emits an acknowledgement byte after every four bytes / eight hex nibbles. This allows the load tool to rate limit itself and uploads are now much more reliable.

Still no mechanism for getting data off the board though.

thejpster, 2018-12-01:
Should just write a uart ram dump routine.

thejpster, 2018-12-15:
Can load from SD card.

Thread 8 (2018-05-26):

Audio support

thejpster, 2018-05-26:
We have some timers spare, and I'm sure we can generate some audio.

Once a scan line (so 37.680 kHz) set the PWM to output a level between 0 and 255. Add some filtering and buffering on the output pin and voila - 37.680 kHz 8-bit PCM mono audio.  But as we have no room for samples, we probably need an API that lets you play beeps (square waves? maybe even triangle waves using some very basic maths?) at a given frequency for a given number of frames.

We probably want to set the audio output at the end of the scan-line to avoid delaying the video. Maybe calculate at the end of the scan-line and load at the start of the next scan-line.

thejpster, 2018-07-22:
https://sensorium.github.io/Mozzi/ is a synthesizer for Arduino which may work as a reference. Has some output schematics too.

thejpster, 2018-09-02:
See GitHub.com/thejpster/monotron-synth. Needs connecting to a PWM and running from the video interrupt. Not sure how to make it safe to generate samples under interrupt and change parameters in the main thread.

thejpster, 2018-09-02:
Maybe the synth should be optional, incase they want to provide their own synth and just supply pcm samples?

thejpster, 2018-09-16:
So, the LM4F120 has Timers, but they can't do up/down symmetrical PWM. The TM4C123 has Timers, plus two PWM peripherals which can do up/down.

So... I think we're going to have to switch to the TM4C123 as the official platform.

thejpster, 2018-09-16:
Also, www.rakits.co.uk gave me a neat little amplifier, so I need to get that built up.

thejpster, 2018-10-11:
Audio support is merged, and I tried it with the Rakits amplifier. Well, sound comes out, but it's very noisy. Interestingly, if I unplug the VGA cable, the noise drops right down.

* Perhaps the impedance mismatch on the VGA lines is causing this?
* Perhaps they just radiate more noise if they're conducting significant chunks of current? I think we're at about 8.1mA per RGB channel.

If I get the chance, I'll unpack my oscilloscope and see what frequency the noise is, which should give some clue to its source. Otherwise I'll just ignore it for now, and think about the ABI for driving the synth.

thejpster, 2018-10-15:
ABI for driving the synth is in. Snake can go 'bip bip bip boooop'.

Closed 2018-10-22.

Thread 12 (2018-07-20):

Support STM32F3 / STM32F4 Discovery

thejpster, 2018-07-20:
It would be an excellent demonstration of Monotron's (and indeed Rust's) portability if there was an option to compile it for the STM32F3 Discovery. The STM32F3 has 256 KiB Flash and 48 KiB RAM (a Monotron 48K!) and a 72 MHz clock speed, which would give a VGA resolution of 800 x 600 @ 56 Hz or 640 x 480 @ 85 Hz - for compatibility the former would be better, but frame-locked games would run a little slower.

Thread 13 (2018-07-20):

Extra graphics modes - 384x288 with 8x8 cell based 3bpp colouring

thejpster, 2018-07-20:
Currently we have a 50x36 text buffer consuming 3,600 bytes, where we take the first and last colour as a border.

I propose a 384*288 1bpp framebuffer mode which takes colours from the text mode colour attributes. This would add 13,824 bytes but could be enabled on a line-by-line basis. There would be a slow-copy routine for blitting in arbitrary size bitmap into an arbitrary location, and a fast-copy routine for blitting a bitmap a multiple of 8 wide (an integer number of u8s) into a location that was a multiple of 8. The latter would be useful for writing characters to the display. We'd need to add an 8x8 font in addition to the 8x16 font for text mode, as we have 288 rows with line-doubling, not the 576 rows of text mode.

The function to enable graphics mode could take a buffer that was some multiple of 48 bytes and an odd scan-line to stitch the buffer in at. This would allow split-screen modes, with text at the top and bottom and graphics in the middle. The switch for text vs graphics is performed once per line and so isn't expensive, and both graphics and text ultimately go out to the same SPI FIFOs through the same colouring routines so graphics mode shouldn't be slower. If anything, without the font lookup it might be quicker.

Total memory used = 17,424 bytes max.

thejpster, 2018-08-27:
1bpp framebuffer implemented. Needs drawing routines.

thejpster, 2018-09-16:
Closed in favour of #23

Closed 2018-09-16.

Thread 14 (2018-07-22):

Memory map

thejpster, 2018-07-22:
To load programs into RAM, we need to fix the memory map so they can be linked correctly.

This is complicated by the fact that video memory increases massively if we enter graphics mode. I'm sure the BBC and the C64 have some useful guidance on how to deal with this.

thejpster, 2018-09-16:
Currently I'm working off whatever the application ram variable happens to be linked at at the moment. I need to move it to `0x2000_0000` so it's consistent.

thejpster, 2018-09-16:
Entering graphics mode requires the application to provide it's own frame buffer, taken from the application RAM block, so that's fine.

thejpster, 2018-12-01:
Fixed with a structure full of syscall function pointers

Closed 2018-12-01.

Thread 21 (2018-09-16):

Switch to TM4C123

thejpster, 2018-09-16:
For USB support and PWM support (proper PWM, not just Timers in PWM mode) we're going to need a TM4C123 instead of an LM4F120.

Unfortunately when I tried the TM4C123 I got a bunch of video noise. I don't know if the output circuits are different, but I need to fix that.

- [x] Update README
- [x] Update comments

Closed 2018-09-27.

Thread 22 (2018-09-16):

Fix video noise

thejpster, 2018-09-16:
On the TM4C123 there's bad video noise, especially in the border on blank lines.

I think I need to make a better VGA interface with much much shorter cables.

thejpster, 2018-09-24:
In extremis, we could use an [AD813ANZ](https://uk.rs-online.com/web/p/operational-amplifiers/7097067/) triple-channel video amplifier. But it's about £9.

thejpster, 2018-10-23:
Or a couple of cheap op-amps? https://www.proto-pic.co.uk/op-amp-thru-hole-lm358.html

thejpster, 2018-10-23:
Analog have a ton of parts, even one that's a PDIP.

https://www.analog.com/en/parametricsearch/11117#/p2687=|3|4&p4502=50000000|1000000000&ps5=14%20ld%20PDIP|14%20ld%20PDIP%20(300%20mil)|16%20ld%20PDIP%20(300%20mil)|8%20ld%20PDIP|8%20ld%20PDIP%20(300%20mil)

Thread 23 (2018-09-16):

Add drawing routines

thejpster, 2018-09-16:
Add routines for this to the vga-framebuffer crate, and to the API.

- [ ] Line drawing
- [ ] Rectangle drawing
- [ ] Filled rectangle drawing
- [ ] Bitmap copy

thejpster, 2018-10-15:
Unsure if this API should be on the `FrameBuffer` or on some `Canvas` struct which can be plugged into the FrameBuffer (where at the moment we plug in a mutable reference to an array).

MabezDev, 2018-10-16:
If you haven't heard of [`embedded-graphics`](https://github.com/jamwaffles/embedded-graphics) yet, it might be of use. It recently got support for colour displays.

thejpster, 2018-10-17:
I've heard of it, but I don't know how it would tie in with my weird block colour attributes.

MabezDev, 2018-10-19:
Provided you pass a struct that implements the  `PixelColor` trait you can pass whatever you need. Then when you implement the `Drawing` trait, you will get access to all the stuff you need to actually draw that pixel with a colour.

For example in my [ssd1351 driver](https://github.com/MabezDev/ssd1351):

```rust
#[cfg(feature = "graphics")]
impl<DI> Drawing<PixelColorU16> for GraphicsMode<DI>
    where
    DI: DisplayInterface,
{
    fn draw<T>(&mut self, item_pixels: T)
    where
        T: Iterator<Item = drawable::Pixel<PixelColorU16>>,
    {
        let (width, height) = self.display.get_size().dimensions();
        for drawable::Pixel(UnsignedCoord(x, y), color) in item_pixels {
            if x <= width.into() && y <= height.into() {
                self.set_pixel(x, y, color.into_inner());
            }
        }
    }
}
```

thejpster, 2018-10-19:
Ah, the problem is each colour has to apply to a block of 64 pixels. If you have already used, say, red and yellow within a 64 pixel block, it's not defined what should happen if you then want to draw a blue pixel.

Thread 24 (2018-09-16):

Joystick support

thejpster, 2018-09-16:
Atari 9-pin joystick interface.

Console-side joystick port seen from the front.

1. Up
1. Down
1. Left
1. Right
1. Paddle B
1. Trigger
1. +5 volts power
1. Ground
1. Paddle A

Joysticks pull pins to ground. We can ignore (i.e. N/C) the Paddle pins. I guess some sticks might need power?

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

thejpster, 2018-09-27:
I now have an Atari 2600 joystick for testing.

thejpster, 2018-10-19:
This is in 0.6.2, but I've accidentally put fire on PF0 instead of PF4. It's fine, it's just on the other pin header.

thejpster, 2018-10-19:
The pin mixup is now fixed in master. Not worth a 0.6.3 though.

Closed 2018-10-19.

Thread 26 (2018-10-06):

Video jitter

thejpster, 2018-10-06:
I think I've worked out why there's visible jitter on the video - I think it's variable interrupt latency. From what I've read, it seems the interrupt latency can be affected by whatever code you happen to be running when the interrupt occurs. This is further exacerbated by the fact that at 80 MHz we must run the flash at 40 MHz and endure wait states. Some random thoughts follow:

* The latency of the scanline draw routine doesn't matter as we have a FIFO.
* We should consider moving the start of the scanline draw routine to the start of the front porch, to build up an extra 1us (16 or 24 pixels) in the buffer.
* It might be possible to fix the jitter in the SPI start routine by setting the timer to interrupt early, and then busy-waiting on a timer value.
* Just ahead of that busy-wait routine it may be necessary to read an 80 MHz timer value and conditionally jump to a routine with an appropriate number of nops to accurate set our phase relative to the divided 20 MHz pixel clock. In psuedo code:

```
let jumps = [ one_nop, two_nops, three_nops, four_nops ]
let t = read_timer();
function = jumps[t & 0x03];
function();
```
* Another approach is to run the SPI output constantly, outputting zero bytes when there's no signal. So once 50 bytes of visible data have been sent, we simply have to write another 16 bytes to get us across the sync pulse, and we're done! We then only have to start the SPI peripheral once (maybe once per frame, so we're not busy during the v-sync period), and make sure we never underflow! For reference, the SPI FIFO stores 8 words. If we wind it up to 16-bit words, we buffer twice as much (but make the sync-start routine take twice as long).

thejpster, 2018-12-01:
Or we can set another timer isr which just nops a lot, at a priority just one lower. The jump into the start routine is then always from this isr.

thejpster, 2018-12-01:
We could also put the routine in RAM.

thejpster, 2019-04-30:
> Or we can set another timer isr which just nops a lot, at a priority just one lower. The jump into the start routine is then always from this isr.

I fixed this in this way, but with a `wfi` instead of a `nop`. Putting routines in RAM helped, as did moving the vector table, but with this fix it runs fine with them in a flash, so I put them back.

See 4d1a9b7

Closed 2019-04-30.

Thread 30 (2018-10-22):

Audio jitter

thejpster, 2018-10-22:
The PWM update is in the wrong place.

thejpster, 2018-10-23:
Dupe of #29 during github outage.

Closed 2018-10-23.

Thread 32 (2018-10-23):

Real time clock and date/time support

thejpster, 2018-10-23:
It would be nice if we had:

* Internal time-of-day support (available to the OS). To start, we'd prompt for date and time on boot like MS-DOS does when the battery is flat. The Launchpad comes with a 32,768 Hz crystal.
* External battery backed RTC support. See https://www.proto-pic.co.uk/ds1307-i2c-real-time-clock-module.html. Or can we add a battery to the hibernate module on the Tiva-C?

thejpster, 2018-10-23:
This then opens questions like time zones...

thejpster, 2018-12-01:
Kalin have me an RTC module for a Raspberry Pi. Should work.

thejpster, 2018-12-01:
Also, date/time support needed for FAT support.

thejpster, 2019-08-25:
All done

Closed 2019-08-25.

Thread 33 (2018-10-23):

SD/MMC support

thejpster, 2018-10-23:
We can put an SD card on SSI0 and use it to load/save files. Breakout boards aren't too expensive (https://www.proto-pic.co.uk/sdmmc-card-breakout.html)

See https://github.com/rafalh/rust-fatfs

thejpster, 2018-12-01:
See WIP PR. Can currently do a dir on the root directory.

thejpster, 2018-12-09:
We also need a DOS to handle the card, and to expose a sensible API to the user.

The Linux syscall API / POSIX file API isn't a bad starting point I guess.

thejpster, 2018-12-15:
See #46

thejpster, 2018-12-15:
The WIP PR can now load 6502 BASIC from the SD card (which is about 4 clusters in length).

thejpster, 2018-12-22:
We need to use DMA so that data can be transferred during the video render as currently the performance is terrible. Changing the video to use a non-blocking pull API and SPI FIFO space free interrupts would also help.

thejpster, 2018-12-22:
There is some DMA example code in a branch for doing DMA with the frame buffer. We can adapt that to do DMA with the SPI instead.

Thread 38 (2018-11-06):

CPU monitor

thejpster, 2018-11-06:
The wfvbi() API could grab a timer value (maybe SysTick @ 1MHz or something) on entry and exit, and return some fractional value to indicate how loaded the CPU is - maybe a number between 0 and 99. You can then display this on screen in your game to know how much more 'work' you can do each frame.

thejpster, 2018-12-26:
You can configure a system timer to increment only when CPU is active, not when CPU is asleep - if you compare this against another system timer that runs always, you can easily compute CPU usage during the intervening period.

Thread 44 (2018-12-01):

TM4C129

thejpster, 2018-12-01:
This has 1 MiB flash, 256 KiB RAM, 120 MHz clock speed, an Ethernet MAC and an external bus interface (so I could have more colours via a resistor DAC). Even 80 column mode should work. But is it too much?

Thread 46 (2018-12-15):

Add file I/O to the ABI

thejpster, 2018-12-15:
Need to be able to read/write files and list directories from the Apps, e.g. loading bitmaps/code from disk.

thejpster, 2018-12-22:
MS-DOS offered a bunch of virtual files you could open:

* COM1, COM2, ...
* AUX
* LPT1, LPT2...
* NUL
* etc

Linux/UNIX has virtual devices in /dev which acheive the same effect.

In Monotron the devices we want to perform file I/O (read, write, etc) on are:

* SDMMC interface (raw disk access)
* Files in a directory
* Directories (a special case of read) on a given volume
* Open volumes on a given disk
* Serial Interface (UART0 over USB and UART1 over TTL/RS-232) at various baud rates
* Raw SPI interface (with separate chip-select to the SD card)
* I2C interface (with addressing?)
* The text console (with cursor moves, and colours)
* The graphics frame buffer
* The keyboard  (as CP850 bytes, as Unicode UTF8 bytes and as raw scan-codes for games).
* The joystick
* The synthesiser output (3 channels)
* The raw PCM output (into a ring buffer)

thejpster, 2019-09-28:
An alternative approach is to provide a BIOS-level API (enumerating fixed disks, read/write sectors, etc) and moving file read/write into a DOS. This could be loaded into RAM or stored in ROM, but it would be distinct from the BIOS. CP/M does something similar. It would allow us to keep the OS the same on multiple platforms, while the BIOS deals with high-speed SDMMC vs 1-bit SPI, for example. It would effectively be a HAL.

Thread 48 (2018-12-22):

Printer support

thejpster, 2018-12-22:
It would be fun to add Printer Support. There's two primary interfaces:

* Old IBM LPT interface (8-bit parallel with control signals)
* USB Printer

Obviously the latter requires USB host support but I think the first option is acheivable with an SPI or I2C I/O expander and some bit bashing. It wouldn't be fast, but it should work.

I have an old Panasonic dot-matrix I can test with. We would add LPT: as a device type you can open, along with disks, joysticks, keyboard and the screen.

thejpster, 2018-12-22:
A Microchip MCP23S17 or MCP23017 would be ideal. An IEEE1284 'Centronics' interface has 8 data pins (host to device), 4 control lines (host to device) and 4 status lines (device to host). This matches the 16 pins on the MCP23x17. The MCP23x17 also has two interrupt lines, which we can use to avoid busy-waiting on the status lines, transferring bytes under interrupt from a small ring buffer.

The SPI version would have to share with the SD/MMC interface, but the I2C version could just sit on the I2C bus. Using I2C (which is open-drain) would also allow us to run the MCP23017 at 5V without needing level shifters either on the GPIO device input/output pin, or between the GPIO device and the host (because it's open-drain and the Launchpad is 5V tolerant).

So, we should use the MCP23017 for parallel printer support.

thejpster, 2019-01-16:
The PCB has an Atmega48 wired up to the printer port.

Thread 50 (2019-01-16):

Write the AtMega48 firmware

thejpster, 2019-01-16:
The AtMega48 drives the two PS/2 ports and the LPT port. It'll need firmware.

There's only 4 KiB flash and 512 bytes RAM so it'll need to be compact!

I propose a basic command/response protocol:

Commands:
0x00 - Reset to serial bootloader (may not implement this)
0x01 - Get keyboard data
0x02 - Get mouse data
0x03 - Get LPT status
0x04 <len> <data...> <CRC> - Write LPT bytes to buffer
0x05 <Fx> - Write LPT status bits x
0x06 <Fx> - Set keyboard LEDs x

Responses:
0x00 - Will reboot
0x01 <num> <data...> <CRC> - Keyboard data (raw PS/2 Scan Code Set 2)
0x02 <num> <data...> <CRC> - Mouse data (raw PS/2 mouse data bytes)
0x03 <status> - LPT status
0x04 - Write LPT byte confirmed
0x05 - Write LPT status confirmed
0x06 - Write keyboard LEDs confirmed

This should keep the number of bytes in the Cortex-M4's UART buffer to a minimum (it's only 16 bytes long), and allow the Cortex-M4 to only ask for keyboard data when it's not drawing video.

The AtMega48 will handle keyboard init and mouse init on start-up. It will also handle the handshaking with the printer.

thejpster, 2019-08-18:
Ugh. I couldn't face writing C or C++ for AVR so I bought some STM32F0 chips in TSSOP-20 package, and some TSSOP-20 to DIP adaptors.

On the next PCB revision, the PS/2 connectors will be on a riser PCB with the keyboard controller. You can then remove this and fit a USB keyboard controller instead if desired.

thejpster, 2019-08-18:
You could even do a riser board which supported a scan matrix GPIO keyboard (e.g. a C64 keyboard, or an Amiga keyboard).

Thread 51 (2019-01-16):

Write a MIDI driver

thejpster, 2019-01-16:
The PCB has MIDI in and MIDI out. We need a MIDI driver that allows applications to send and receive MIDI events. Or at the very least some test code.

thejpster, 2019-08-18:
Basic `mplay` and `mterm` commands added.

thejpster, 2019-08-18:
But MIDI should be a device you can open, where you can then read and write MIDI events.

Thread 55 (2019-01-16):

Bring up the PCBs

thejpster, 2019-01-16:
- [ ] Receive PCBs
- [ ] Check power in
- [ ] Check VGA out
- [ ] Check audio
- [ ] Check SD/MMC
- [ ] Check joystick
- [ ] Check RS-232
- [ ] Check MIDI Through
- [ ] Check MIDI In
- [ ] Check MIDI Out
- [ ] Check RTC
- [ ] Check Atmega runs OK (need test firmware)
- [ ] Check Atmega comms
- [ ] Check Atmega connection to LPT port
- [ ] Check Atmega connection to PS/2 keyboard port
- [ ] Check Atmega connection to PS/2 mouse port

thejpster, 2019-01-21:
VGA is fine. https://twitter.com/therealjpster/status/1087475018542563334
SDMMC needs 47k pull-ups to 3.3v on CS, MOSI, MISO and SCK otherwise the card isn't detected.
It also needs a current limiting resistor or a big capacitor on Vcc, as inserting a card causes the CPU to reboot - it's probably tripping the brown-out circuit? https://twitter.com/therealjpster/status/1087475302249517057

thejpster, 2019-01-26:
Audio is fine. Joystick is fine too, but my joystick is broken :(

thejpster, 2019-01-26:
UART TX for RS-232 and UART TX for MIDI looks OK. Need to check input with a loopback cable and some a UART test function.

thejpster, 2019-02-06:
PS/2 connector footprints are backwards. Connectors need to be fitted to reverse of PCB.

thejpster, 2019-02-06:
UART RTS/CTS was wrong in software. Fixed, and tested by sending > 16 chars to Monotron using `screen /dev/ttyS4 115200,crtscts`. Noted that RTS line went high when 8 chars received (FIFO half-full).

thejpster, 2019-02-10:
Now I have a null-modem cable, I've checked the MAX3232 circuit - seems fine. RS-232 voltages are +6V/-6V. Was able to dump a large text file in using Bray Terminal and it respected the RTS from the Monotron and avoided UART FIFO overflow.

thejpster, 2019-02-10:
Tested MIDI In with my Drum synth and valid MIDI bytes appeared OK. Connected MIDI Out to MIDI In with a cable (so, a loopback test) and any bytes I sent were received OK.

thejpster, 2019-02-10:
Updated schematic to rev 0.8.0:
* Added SD activity LED
* Connected INIT to the MCU via the two spare hex inverters
* Moved SELPRIN to pin INIT was using
* PC6 (former SELPRIN) as Atmel RESET
* Added ISP header for Atmel programming
* Added SMT microSD footprint
* Added 47k SD pull-ups

I can probably add the LPT wiring changes onto the two 0.7.0 boards I've built. Will need to cut two tracks to the LPT port and some bodge wires.

thejpster, 2019-02-20:
Tested RTC. Can read and write registers ok.

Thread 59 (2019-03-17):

Dual Genesis/MegaDrive pad support

thejpster, 2019-03-17:
I've concluded we need two joystick inputs, so we can have two player games. It would also be good to support MegaDrive pads (mainly as I have two of those anyway).

A MegaDrive pad has 6 active-low output pins, and a 5V input select signal, giving a total of 12 possible outputs from the pad. These are Up, Down, NC, NC, A, Start, Up, Down, Left, Right, B, C.

We currently have five inputs for the Joystick, plus two unused pins. We have no pins free on the Atmega (actually we have minus 1 free pins). Using an [MCP23S17](https://www.microchip.com/wwwproducts/en/MCP23017) we can handle the 12 inputs, and two select outputs using our existing I2C bus interface, freeing up 5 I/O pins (one of which is an active-low button on the Launchpad anyway).

Or we could upgrade the Atmega to a 40-pin device.

thejpster, 2019-03-17:
We could also use a nifty dual header.

https://www.digikey.co.uk/product-detail/en/amphenol-icc-commercial-products/L17H2110130/L17H2110130-ND/4884779

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

thejpster, 2019-08-25:
The SPI version of the chip might be faster than the i2c version.

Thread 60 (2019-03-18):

Make a box

thejpster, 2019-03-18:
This seems like a nice box. Lots of room. PCB would be 174 mm x 141 mm. The connectors (including two Megadrive DE-9s) just about fit, and there's plenty of board space.

https://uk.rs-online.com/web/p/instrument-cases/2205550/

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

thejpster, 2019-08-18:
So I did spend some (quite a lot actually) of time thinking about making Monotron into an ATX or microATX form-factor. I'd then have a custom expansion connector broadly inline with the expansion slots in the case. But ATX cases are big and bulky and I think I prefer an Amiga 500/1200 style form factor.

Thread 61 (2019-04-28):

Move shell behind monotron-apps ABI

thejpster, 2019-04-28:
The shell is currently baked tightly in to the OS - this means you can't test it separately.

We should split out ui.rs into a separate crate that uses monotron-app, but uses one of a number of specific 'slots' in flash. These can be written independently. You could also get it to mount the SD card and load a shell from SD automatically (autoexec.app?).

This is a similar mechanism to the BBC Micro OS.

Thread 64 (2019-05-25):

VT100 support

thejpster, 2019-05-25:
We should add proper VT100 / ANSI code support

thejpster, 2019-05-25:
I did some testing with a basic C program to see how various non-alphanumeric inputs are encoded:

```C
#include <stdio.h>
#include <stdlib.h>

int main(int argc, char** argv)
{
	system( "/bin/stty raw" );
	while ( 1 ) {
		int input = getc( stdin );
                printf( "Read %d (0x%02x)\r\n", input, input );
		if ( ( input == 3 ) || ( input == EOF ) ) {
			break;
		}
	}
	system( "/bin/stty cooked" );
	return 0;
}
```
Results (two bytes is a hex byte, single char is ASCII, ESC is 0x1B):

Key | Result |
----|-------|
Up Arrow | ESC [ A  |
Down Arrow | ESC [ B |
Right Arrow | ESC [ C |
Left Arrow | ESC [ D |
Home | ESC [ N |
End | ESC [ F |
Escape | ESC |
Page Up | ESC [ 5 ~ |
Page Down | ESC [ 6 ~ |
Insert | ESC [ 2 ~ |
Delete | ESC [ 3 ~ |
Backspace | 7f |
Print Screen | Interpreted by GNOME Desktop |
Pause | Ignored |
Break | Ignored |
Sys Req | Did a print-screen |
F1 | ESC O P |
F2 | ESC O Q |
F3 | ESC O R |
F4 | ESC O S |
F5  | ESC [ 1 5 ~ |
F6  | ESC [ 1 7 ~ |
F7  | ESC [ 1 8 ~ |
F8  | ESC [ 1 9 ~ |
F9  | ESC [ 2 0 ~ |
F10 | No effect |
F11 | Made window full-screen |
F12 | ESC [ 2 4 ~ |
Control A | 01 |
Control B | 02 |
Control M | 0d |
Control Z | 1a |
Enter | 0d |

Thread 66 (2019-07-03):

Add ESP-01 support

thejpster, 2019-07-03:
With a small adaptor, containing a 5V to 3.3V LDO (as I don't think the Launchpad's LDO has enough current left to drive an ESP8266), we could connect an ESP-01 (an ESP8266 based WiFi board) to the Monotron. Using the AT command firmware (https://www.espressif.com/sites/default/files/documentation/4a-esp8266_at_instruction_set_en.pdf) Monotron can easily open TCP, UDP and SSL sockets, read/write bytes on those sockets, do DNS lookups, etc.

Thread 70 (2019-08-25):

Use DMA and add async read/write.

thejpster, 2019-08-25:
It would be nice if we didn't have to spin while reading from the SD card. We can use DMA to transfer blocks in the background. The API will have to give the user a Future they can poll or resolve later.

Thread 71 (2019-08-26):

The Monotron Platform

thejpster, 2019-08-26:
It would be nice if 'Monotron' was an application you could run on different boards (see #12). @IGBC also wanted to port it to a board with an FPGA based GPU. This is the classic M-N problem.

Bad solution (M*N):
```
CPU Board A +---+ Expansion Board A
             \ /
              X
             / \
CPU Board B +---+ Expansion Board B
```

Better solution (M+N):
```
CPU Board A +                  + Expansion Board A
             \                /
              Common Interface
             /                \
CPU Board B +                  + Expansion Board B
```

The standard microcontroller interfaces are:

* SPI (MOSI, MISO, CLK + unique chip-select per slave device + unique IRQ per accessory)
    * SD cards
    * Ethernet interfaces
* I<sup>2</sup>C (SDA, SCL + unique IRQ per accessory)
    * Real-time clocks
    * Sensors (Temperature, Humidity, Pressure, etc)
* UART (unique RX + TX pair per accessory, plus optional unique CTS/RTS pair per accessory)
    * WiFi Modems
    * Bluetooth Modems
    * RS-232 interfaces

We should endeavour to support all of these, as they all have their uses.

There are several interface pinouts in common use:

* Raspberry Pi 'Hats' (https://www.raspberrypi.org/documentation/usage/gpio/)
* MikroElektronika mikroBUS 'Click boards' (https://www.mikroe.com/mikrobus)
* Arduino Uno 'Shields' (https://www.arduino.cc/en/reference/board)
* Texas Instruments Launchpad 'Booster-packs' (http://www.ti.com/design-resources/embedded-development/hardware-kits-boards.html)
* Beagleboard 'Capes' (https://beagleboard.org/capes)
* STM32 Nucleo 'Expansion boards' (https://www.st.com/en/evaluation-tools/stm32-nucleo-expansion-boards.html)
* Adafruit 'FeatherWing' (https://learn.adafruit.com/assets/78438)

By adding another, we are in danger of:

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

The general idea I think should be:

```
+-----------------+   +-[VGA]-[USB?]-[PWR]-+
| :  :            |   |                    |
| :  :            |===|B                   |
| :  :            |   |R                   |
|                 |   |I                   |
|                 |   |D                   |
|                 |===|G                   |
|     Clik        |   |E                   |
| Expansion Board |   |     CPU Board      |
+-----------------+   +--------------------+

+-----------------+   +-[VGA]-[USB?]-[PWR]-+
|                 |   |                    |
| ::::::::        |===|B                   |
|                 |   |R                   |
|                 |   |I                   |
|                 |   |D                   |
|                 |===|G                   |
|     Pi Hat      |   |E                   |
| Expansion Board |   |     CPU Board      |
+-----------------+   +--------------------+

+-----------------+   +-[VGA]-[USB?]-[PWR]-+
|                 |   |                    |
| ::  ::  ::  ::  |===|B                   |
| ::  ::  ::  ::  |   |R                   |
| ::  ::  ::  ::  |   |I                   |
|                 |   |D                   |
|                 |===|G                   |
| Monotron 4-way  |   |E                   |
| Expansion Board |   |     CPU Board      |
+-----------------+   +--------------------+
```

i.e. a bunch of `M` CPU boards, designed for Nucleo-64, Launchpad, TinyFPGA, etc, and a bunch of `N` expansion boards, offering one or more connectors of a specific type.

They interconnect using our own standard 'Bridge' interface, that carries as many signals as we can reasonably consider.

thejpster, 2019-08-26:
The MBI (Monotron Bridge Interface) will look something like:

* UART[0..3] RX
* UART[0..3] TX
* UART[0..3] RTS
* UART[0..3] CTS
* (16 pins)
* SPI MISO
* SPI MOSI
* SPI CLK
* SPI CS[0..3]
* (7 pins)
* I<sup>2</sup>C SCL
* I<sup>2</sup>C SDA
* (2 pins)
* IRQ[0..3]
* (4 pins)
* GPIO[0..15]
* (16 pins)
* 2x5V (VBUS)
* 2x3.3V (rated at maybe 250 mA?)
* (4 pins)
* Lots of GND

49 pins plus, ground, so say, 64 pins? On a 2x32 header? You'd have a basic sub-set that all CPU boards must implement (I<sup>2</sup>C, one IRQ, one UART, one SPI CS, etc) which allows for one slot. A fully-featured CPU board could handle four slots, with each slot using all three buses.

thejpster, 2019-10-18:
See GitHub.com/neotron-compute

Closed 2019-10-18.

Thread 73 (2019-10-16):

idea - use icd/companion chip as second cpu

fanoush, 2019-10-16:
there are two same cpus on the board, both can be reprogrammed via swd so the main one can be i/o video/audio chip with vga frame buffer in ram and the debugging chip can be main cpu as it has almost no i/o except usb console and gpios used as jtag.

The schematics of whole board is in launchpad user guide on TI site.

thejpster, 2019-10-18:
Really interesting idea!

fanoush, 2019-10-18:
Just to let you know that I managed to attach to both cpus via openocd and stlink v2 clone over SWD and managed to backup flash from icdi cpu and erase and restore it to main cpu and when now attached via device usb connector it is detected as icdi interface too  just with different serial number (maybe the real icdi chip takes the serial from main cpu somehow via jtag), here is how it get detected now, first real icdi via debug usb connector then device usb connector
```
[ 8258.972181] usb 1-1.4.2: new full-speed USB device number 16 using xhci_hcd
[ 8259.077559] usb 1-1.4.2: New USB device found, idVendor=1cbe, idProduct=00fd, bcdDevice= 1.00
[ 8259.077573] usb 1-1.4.2: New USB device strings: Mfr=1, Product=2, SerialNumber=3
[ 8259.077584] usb 1-1.4.2: Product: In-Circuit Debug Interface
[ 8259.077593] usb 1-1.4.2: Manufacturer: Texas Instruments
[ 8259.077602] usb 1-1.4.2: SerialNumber: 0E1015E1
[ 8259.141823] cdc_acm 1-1.4.2:1.0: ttyACM0: USB ACM device
[ 8259.143261] usbcore: registered new interface driver cdc_acm
[ 8259.143269] cdc_acm: USB Abstract Control Model driver for USB modems and ISDN adapters
[ 8276.418142] usb 1-1.4.2: USB disconnect, device number 16
[ 8298.917082] usb 1-1.4.2: new full-speed USB device number 17 using xhci_hcd
[ 8299.022361] usb 1-1.4.2: New USB device found, idVendor=1cbe, idProduct=00fd, bcdDevice= 1.00
[ 8299.022377] usb 1-1.4.2: New USB device strings: Mfr=1, Product=2, SerialNumber=3
[ 8299.022387] usb 1-1.4.2: Product: In-Circuit Debug Interface
[ 8299.022397] usb 1-1.4.2: Manufacturer: Texas Instruments
[ 8299.022418] usb 1-1.4.2: SerialNumber: MFG-TEST
[ 8299.031237] cdc_acm 1-1.4.2:1.0: ttyACM0: USB ACM device
```

here is how i run openocd with stlink V2 (I have stellaris launchpad, maybe for tiva C the ID will be different, it that case it will complain about unexpected id)
```
pi@raspberrypi:~ $ sudo openocd -d2  -f interface/stlink.cfg  -c "set WORKAREASIZE 0x8000" -c "set CHIPNAME lm4f120h5qr" -c "set CPUTAPID 0x2ba01477" -f target/stellaris.cfg
Open On-Chip Debugger 0.10.0+dev-00637-gb3ed97a4 (2019-09-21-21:05)
Licensed under GNU GPL v2
For bug reports, read
	http://openocd.org/doc/doxygen/bugs.html
debug_level: 2
0x8000
lm4f120h5qr
0x2ba01477
Info : auto-selecting first available session transport "hla_swd". To override use 'transport select <transport>'.
Info : The selected transport took over low-level target control. The results might differ compared to plain JTAG/SWD
adapter speed: 500 kHz
Info : Listening on port 6666 for tcl connections
Info : Listening on port 4444 for telnet connections
Info : clock speed 500 kHz
Info : STLINK V2J29S7 (API v2) VID:PID 0483:3748
Info : Target voltage: 3.248085
Info : lm4f120h5qr.cpu: hardware has 6 breakpoints, 4 watchpoints
Info : Listening on port 3333 for gdb connections
Info : accepting 'telnet' connection on tcp/4444

```

for backup and restore I used commands
```
reset halt
flash info 0
flash read_bank 0 stellaris-icdi.bin
```
and
```
reset halt
stellaris mass_erase 0
flash erase_check 0
flash write_bank 0 stellaris-icdi.bin
```
the swd on the 10pin is reversed when compared to info in pdf, when having board upside down with pins in bottom right corner I see this
```
x   x
 o o
 o o = SWCLK (TCK)
 o o
 o o = SWDIO (TMS)
 o o
  x
```
x=holes, o=pins

Anyway, the main info is that both CPUs are accessible via SWD and are identical and usable so this idea may indeed work:-)

When attaching SWD I  powered the board from 3.3V an GND pins in topleft rows  j1 and j3 and both cpus were powered from that and green led was lit.

fanoush, 2019-10-18:
And BTW  this may be useful too if you have two launchpads
http://processors.wiki.ti.com/index.php/Stellaris_LM4F120_LaunchPad_Debug_How_To
then one can debug one launchpad with another when the ICDI chip is not working. However jtag has too many pins, swd is easier with  that tiny 10pin connector for me so I'd prefer openocd with stlink v2 or even native raspberry gpio pins as swd (which works with openocd  too).

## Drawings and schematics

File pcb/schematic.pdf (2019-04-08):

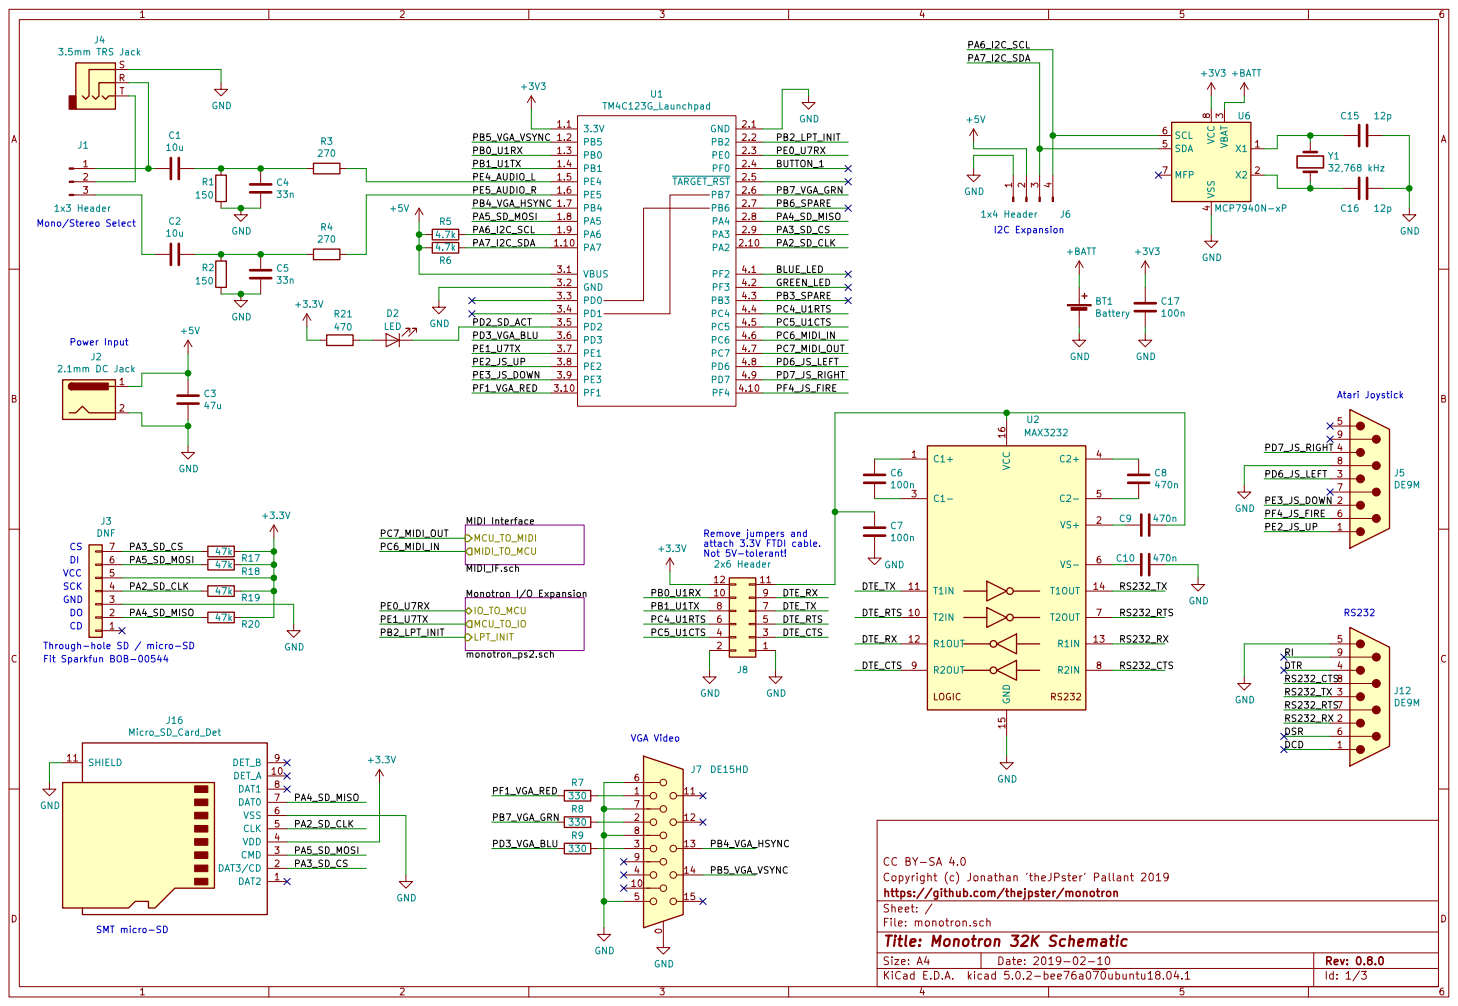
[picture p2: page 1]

4 SDA 5 SCL 6 MFP 7 VCC

attach 3.3V FTDI cable. Not 5V-tolerant! PD2_SD_ACT PE2_JS_UP
PD3_VGA_BLU
PC7_MIDI_OUT MIDI Interface MIDI_IF.sch MCU_TO_MIDI MIDI_TO_MCU

Through-hole SD / micro-SD

Copyright (c) Jonathan 'theJPster' Pallant 2019 CC BY-SA 4.0

File: monotron.sch Sheet: / https://github.com/thejpster/monotron

Id: 1/3 Title: Monotron 32K Schematic

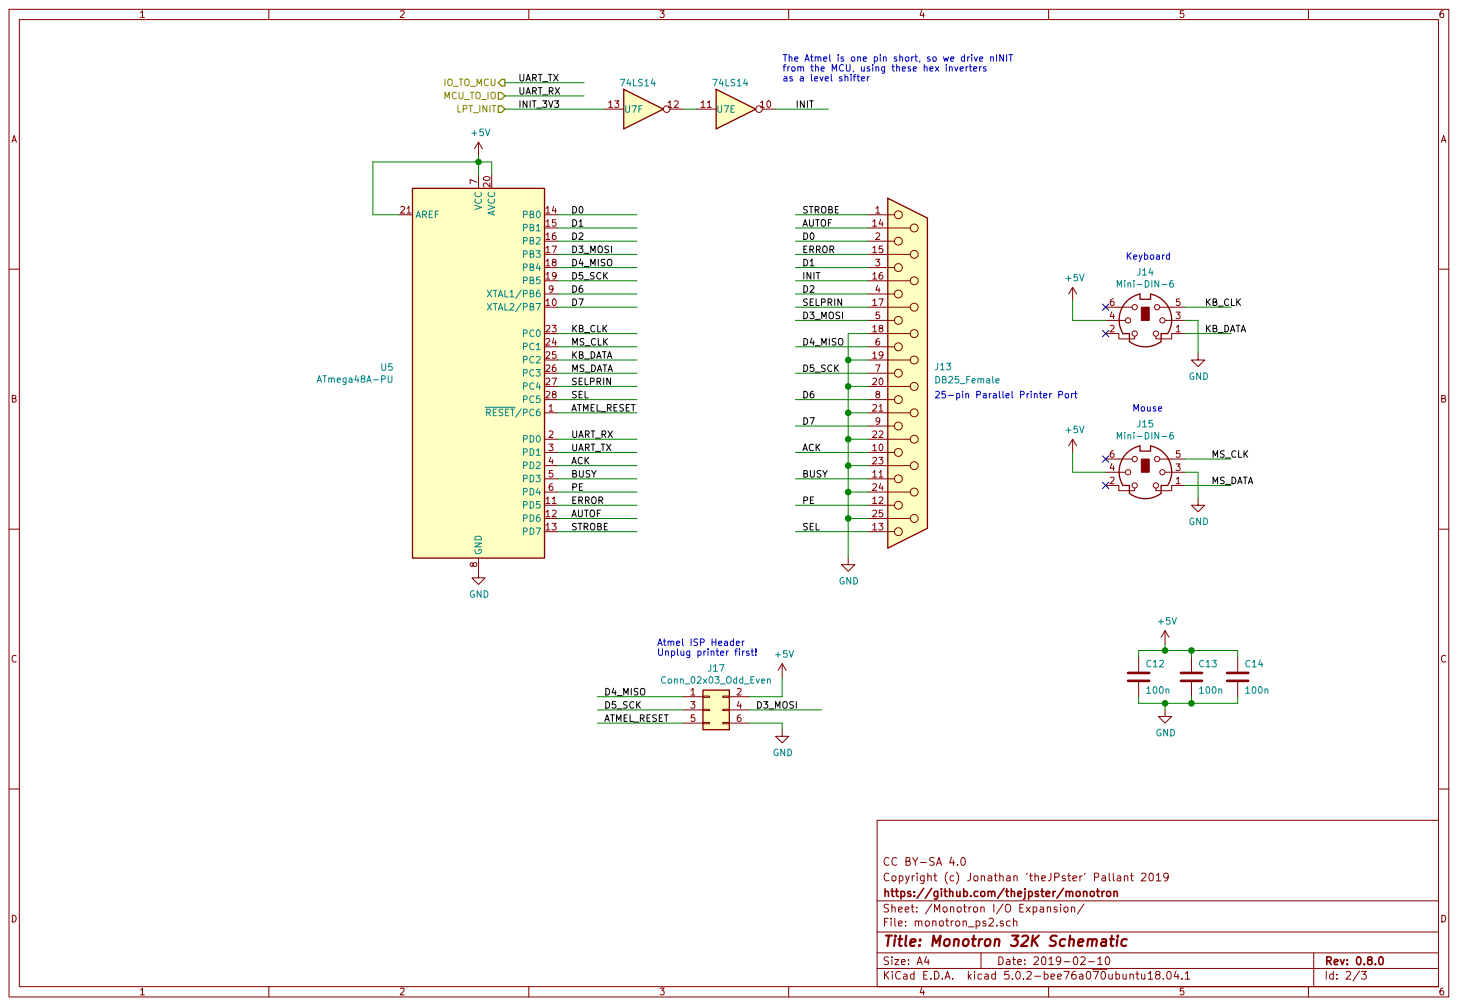
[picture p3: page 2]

from the MCU, using these hex inverters as a level shifter D4_MISO

The Atmel is one pin short, so we drive nINIT

ATMEL_RESET Atmel ISP Header Unplug printer first!

Copyright (c) Jonathan 'theJPster' Pallant 2019 CC BY-SA 4.0

https://github.com/thejpster/monotron
Sheet: /Monotron I/O Expansion/
File: monotron_ps2.sch
Id: 2/3 Title: Monotron 32K Schematic

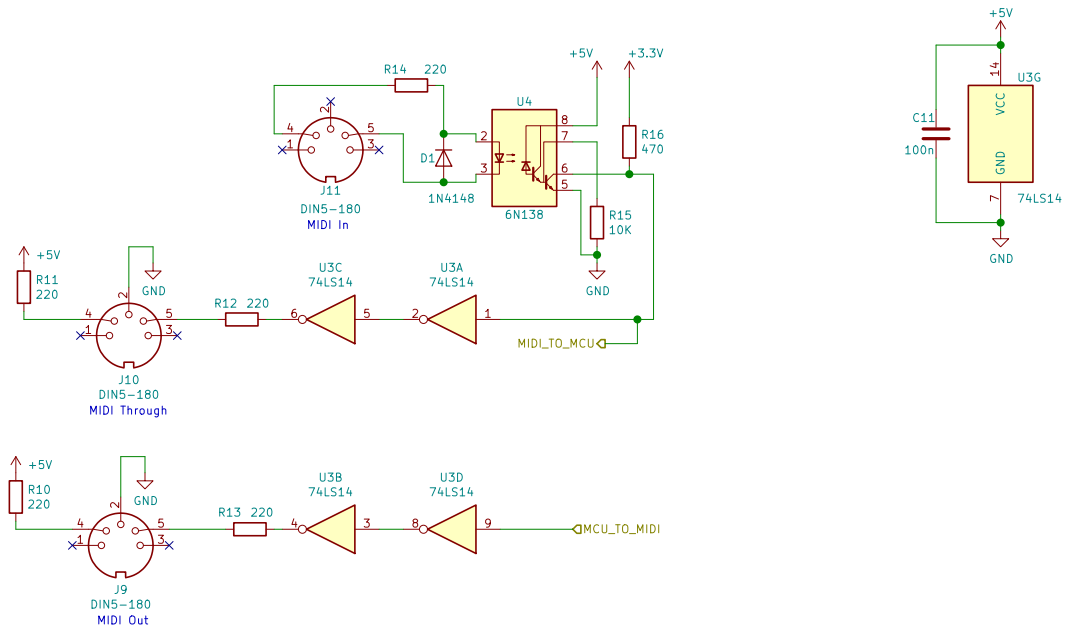
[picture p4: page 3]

Copyright (c) Jonathan 'theJPster' Pallant 2019 CC BY-SA 4.0

File: MIDI_IF.sch Sheet: /MIDI Interface/ https://github.com/thejpster/monotron

Id: 3/3 Title: Monotron 32K Schematic

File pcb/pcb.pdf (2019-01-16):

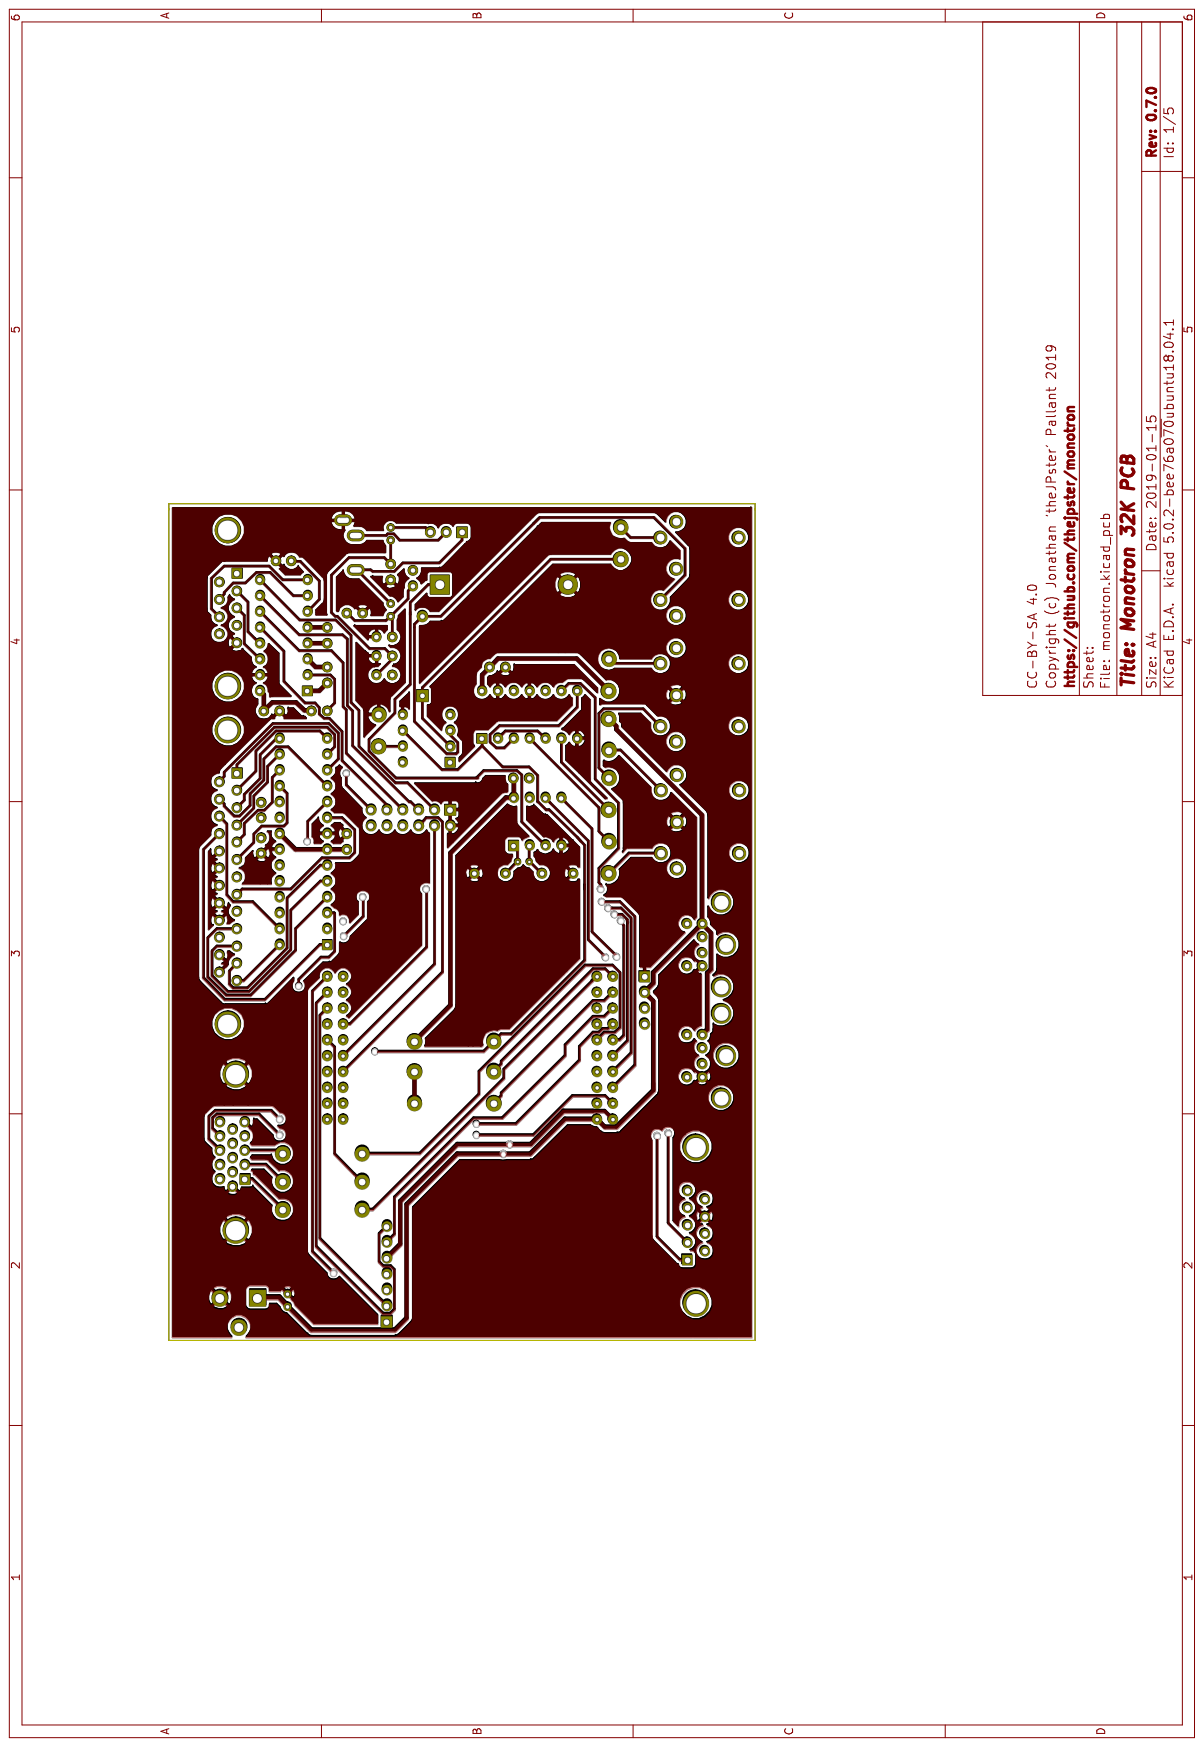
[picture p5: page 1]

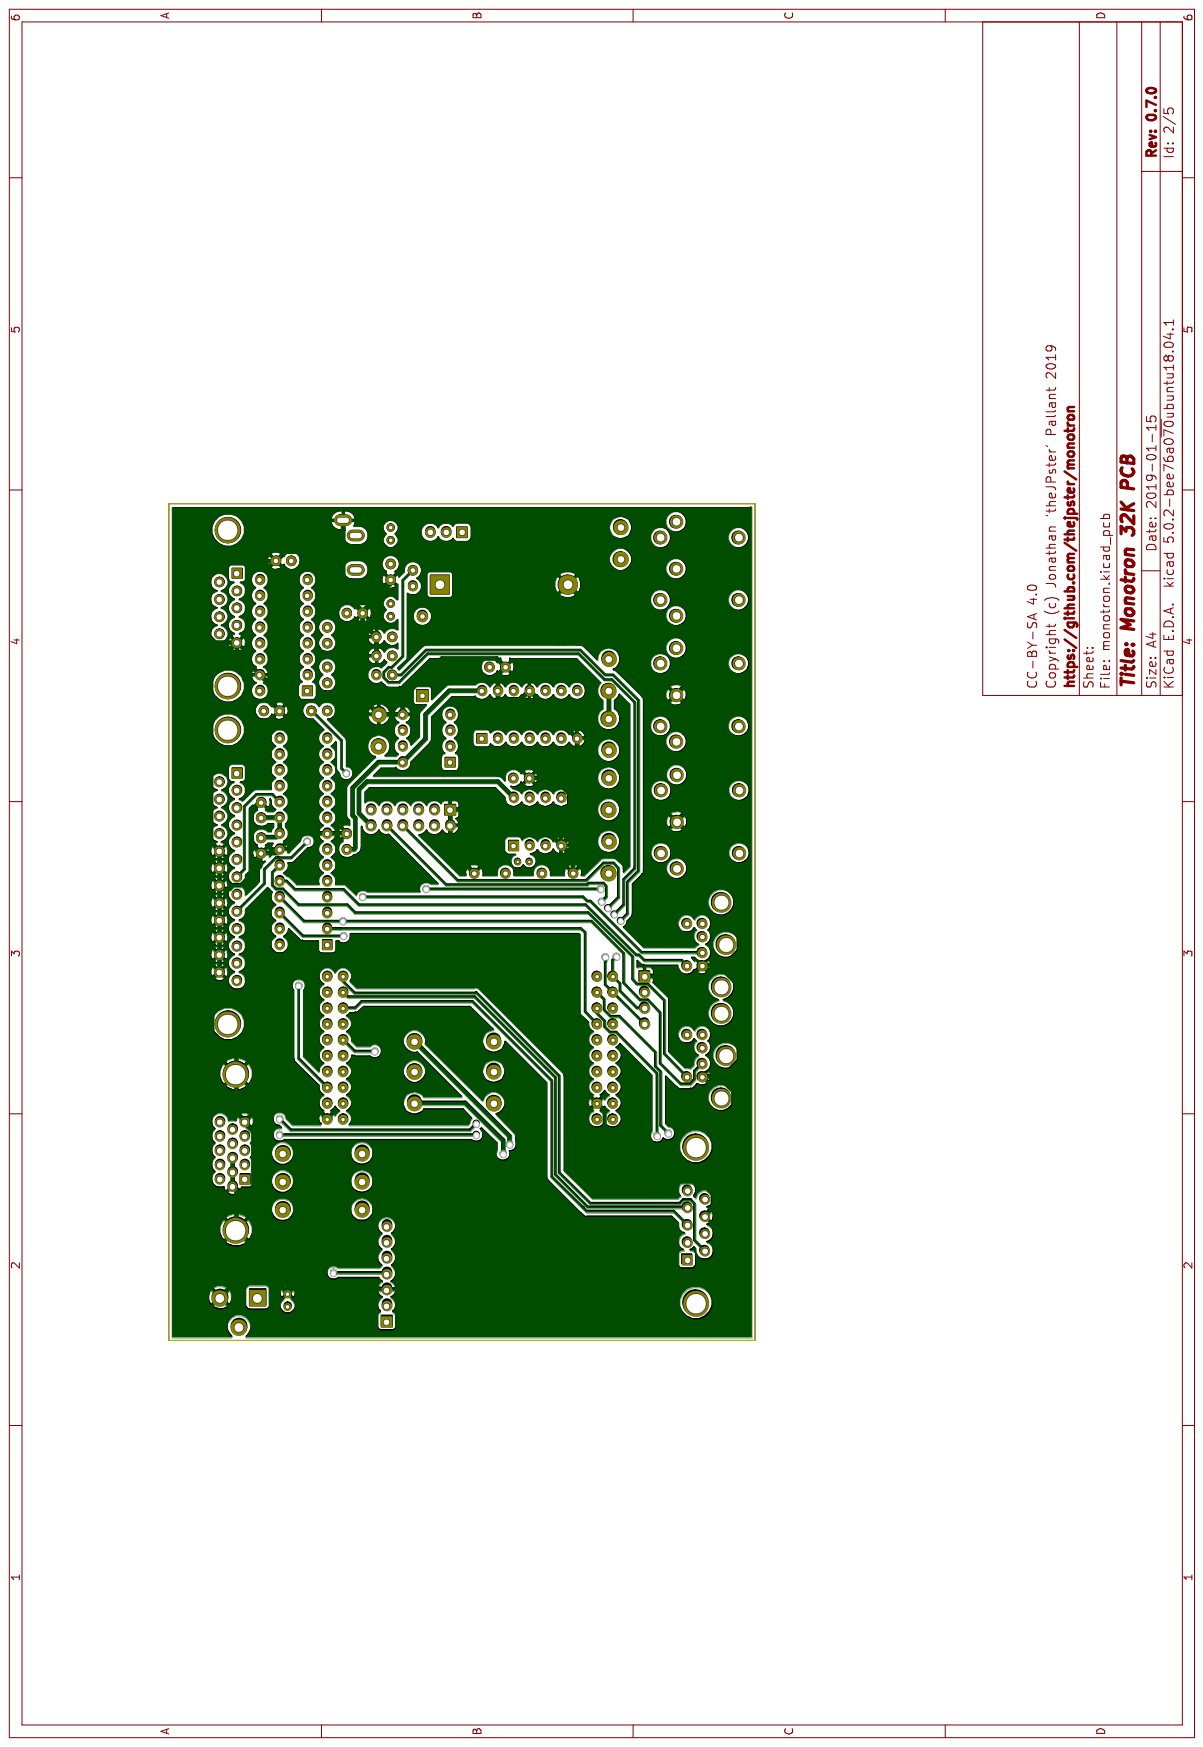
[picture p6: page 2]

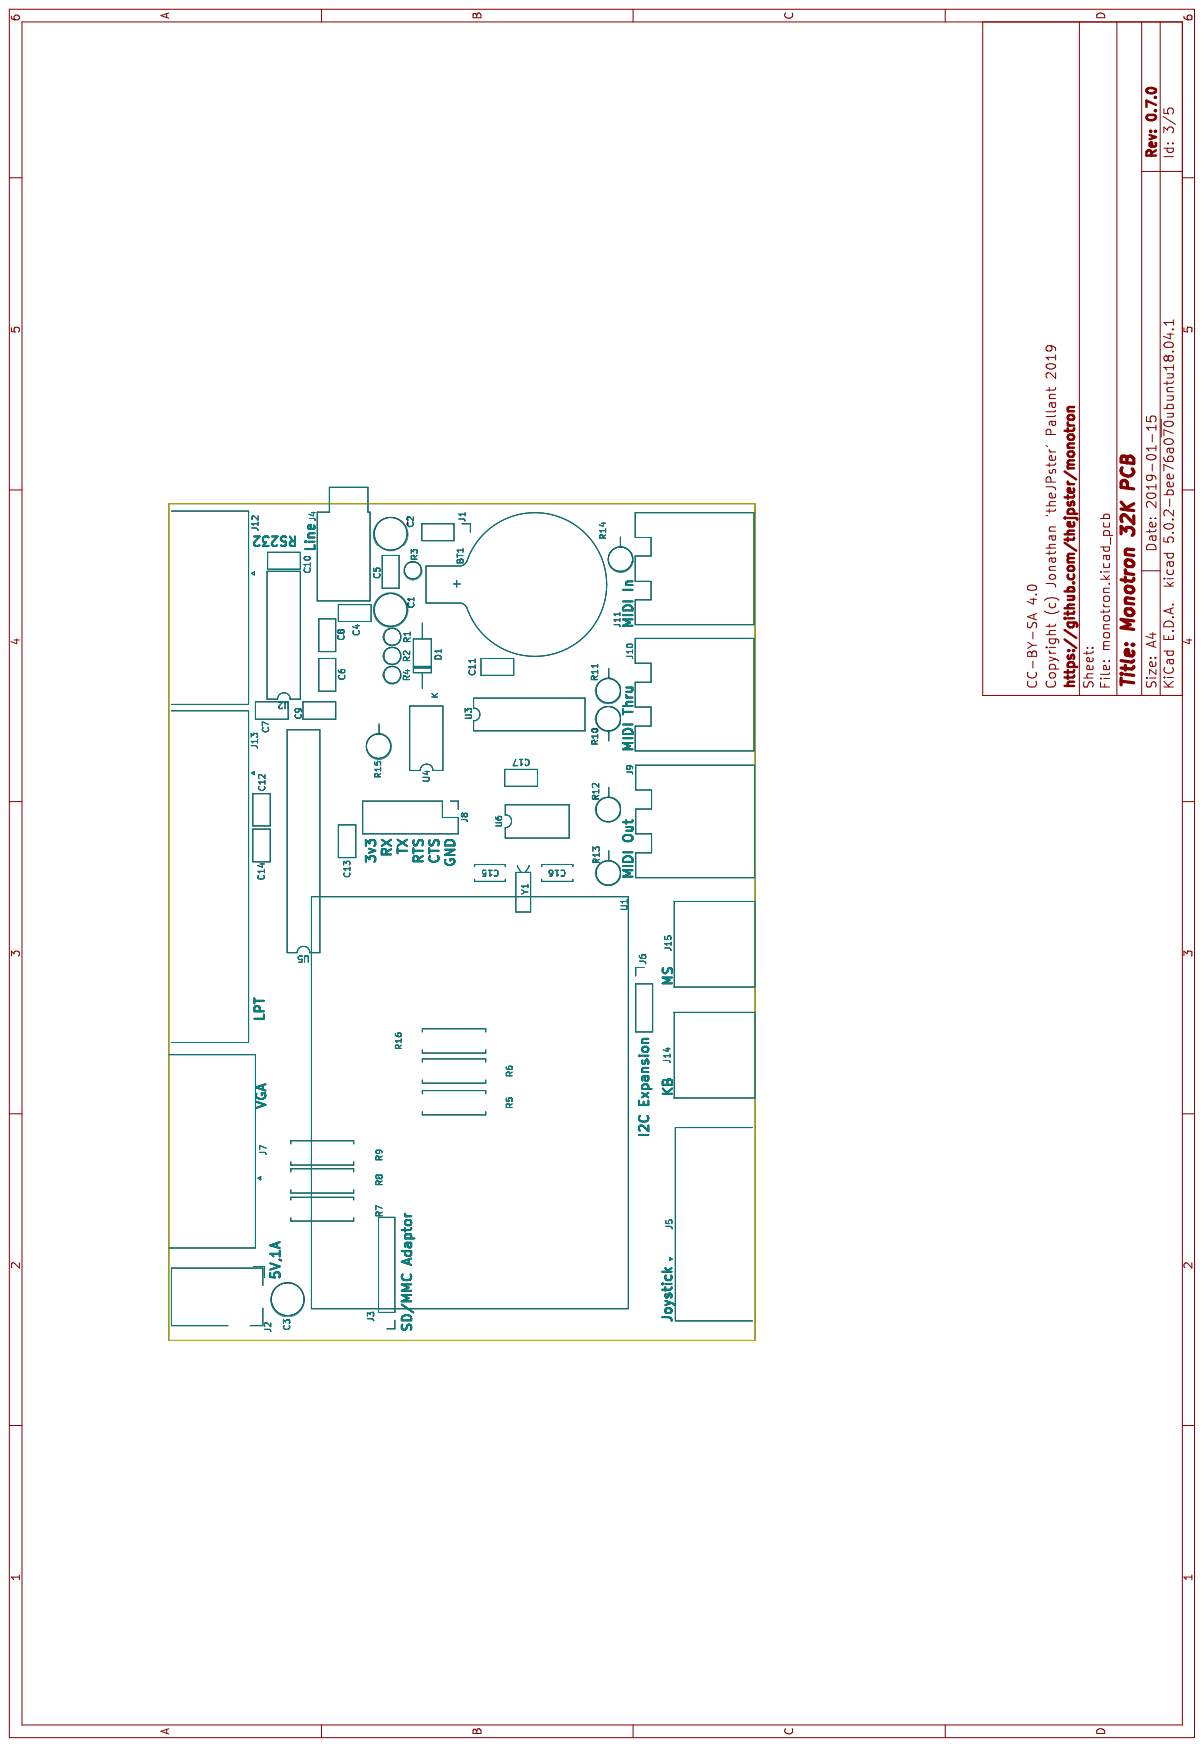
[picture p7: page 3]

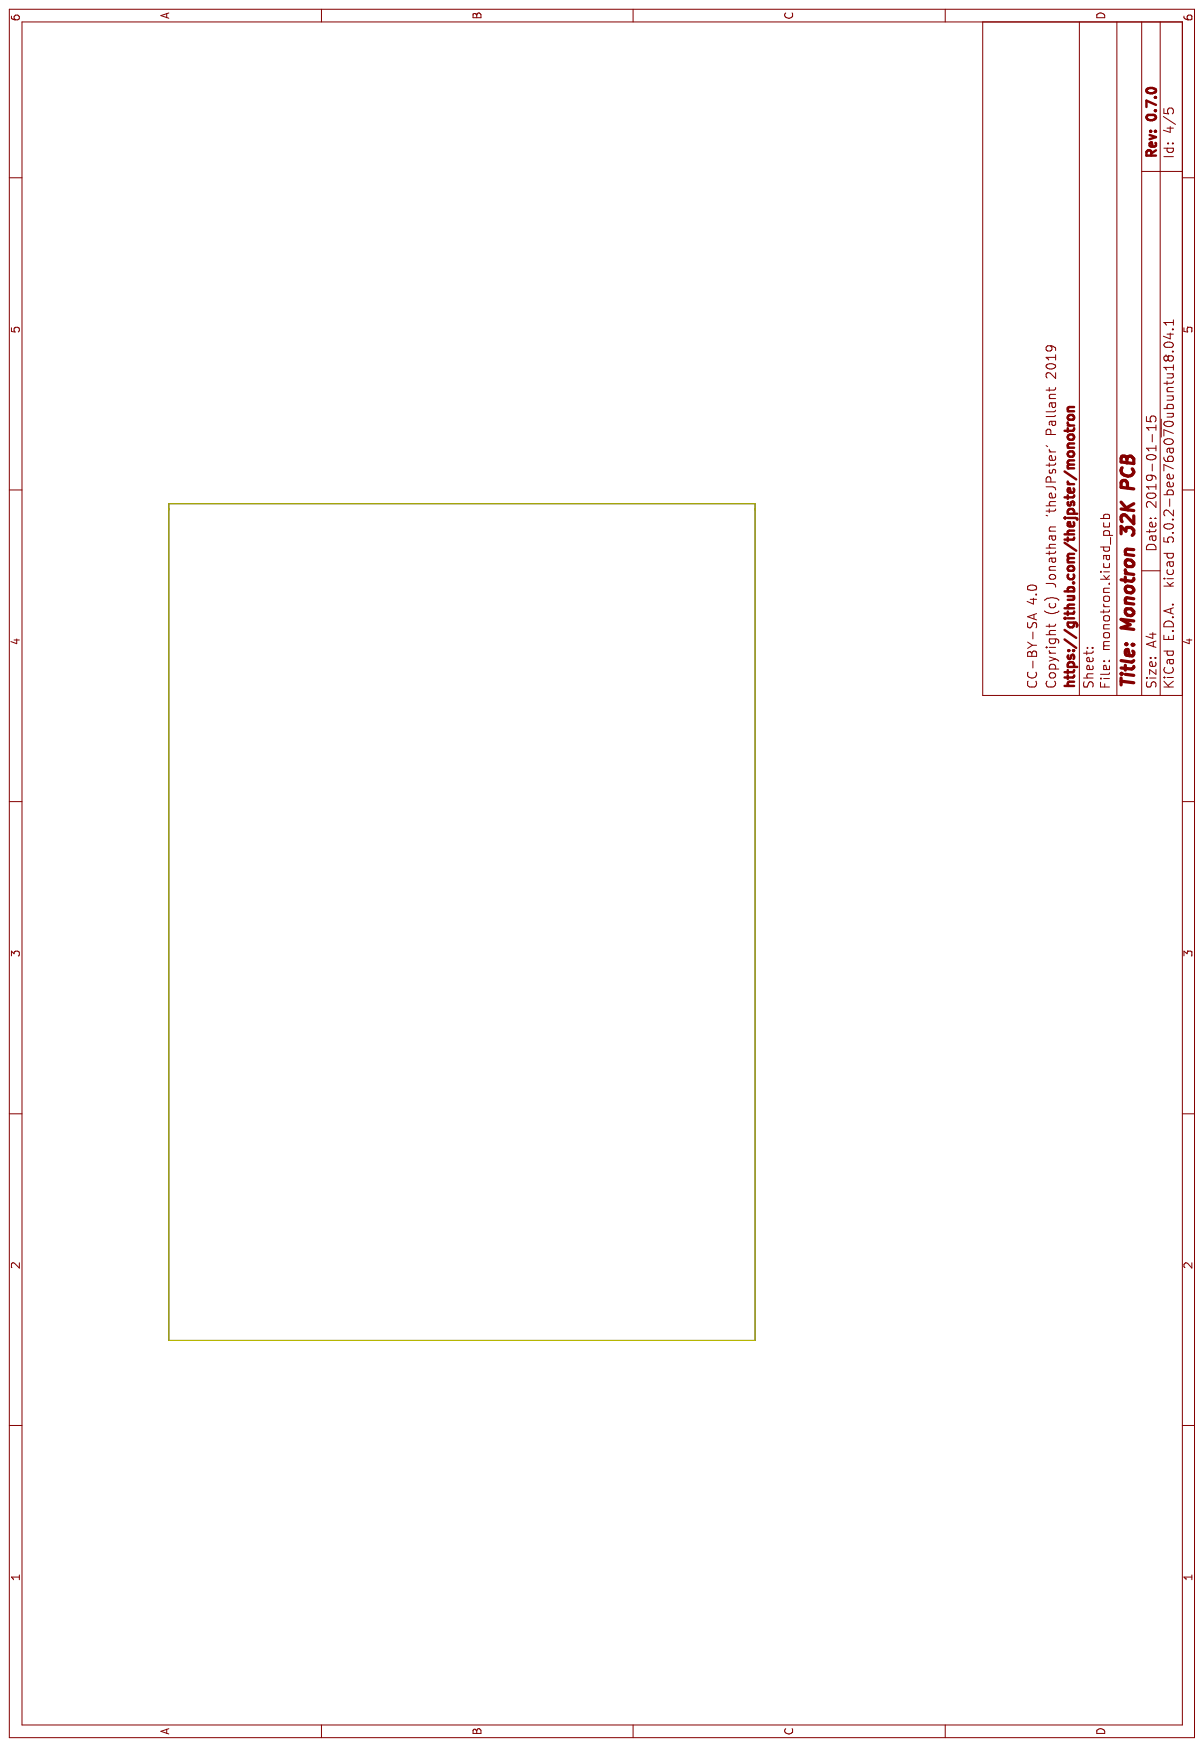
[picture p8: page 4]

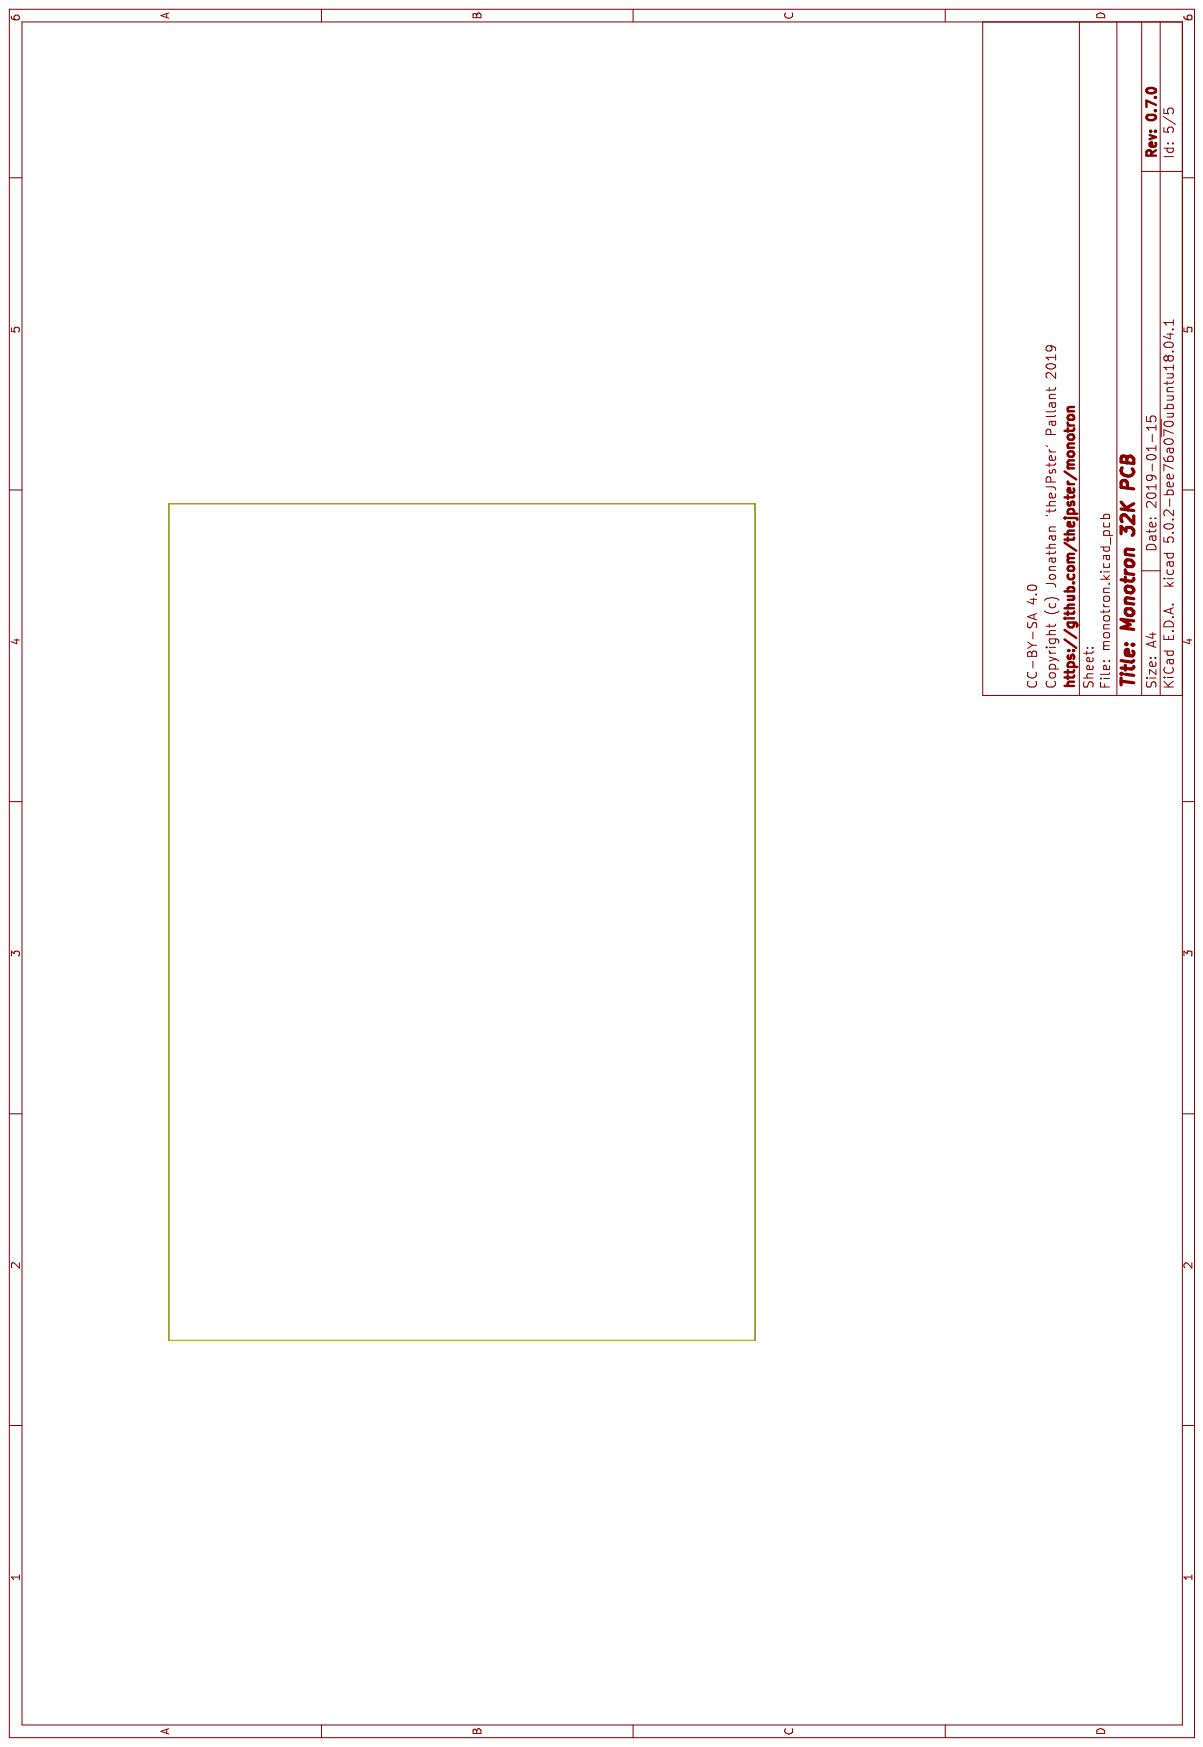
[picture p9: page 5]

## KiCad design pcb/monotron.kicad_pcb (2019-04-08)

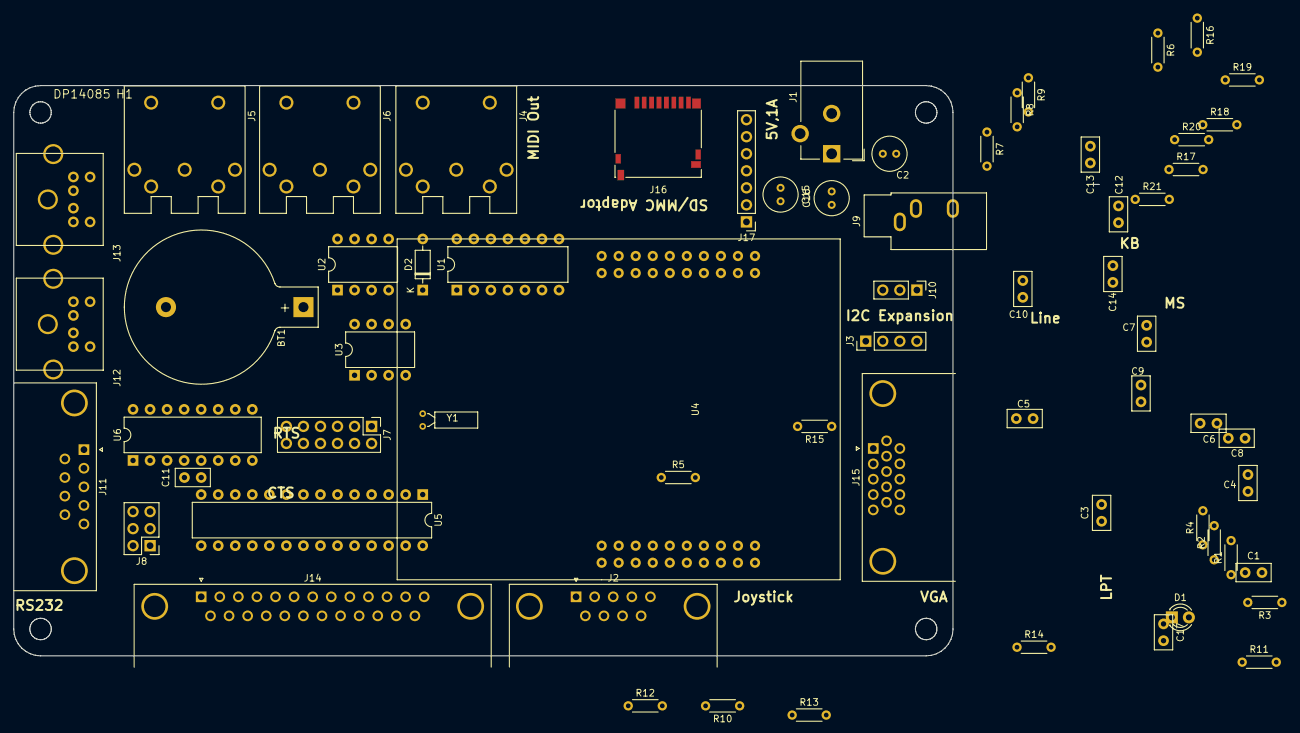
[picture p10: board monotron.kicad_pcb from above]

Board: 2 copper layers, 161.8 x 85.0 mm, 66 parts (0 on the bottom side), 93 nets, no tracks yet.

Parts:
BT1: Battery; BatteryHolder_Keystone_103_1x20mm
C1, C3, C6, C7, C8, C14, C17: 100n; C_Disc_D5.0mm_W2.5mm_P2.50mm
C2: 47u; C_Radial_D5.0mm_H5.0mm_P2.00mm
C4, C5: 12p; C_Disc_D5.0mm_W2.5mm_P2.50mm
C9, C10: 33n; C_Disc_D5.0mm_W2.5mm_P2.50mm
C11, C12, C13: 470n; C_Disc_D5.0mm_W2.5mm_P2.50mm
C15, C16: 10u; C_Radial_D5.0mm_H5.0mm_P2.00mm
D1: LED; LED_D3.0mm
D2: 1N4148; D_DO-35_SOD27_P7.62mm_Horizontal
H1: DP14085
J1: 2.1mm DC Jack; BarrelJack_CUI_PJ-102AH_Horizontal
J2, J11: DE9M; DSUB-9_Male_Horizontal_P2.77x2.84mm_EdgePinOffset7.70mm_Hou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
J3: 1x4 Header; PinHeader_1x04_P2.54mm_Vertical
J4, J5, J6: DIN5-180; 5P180 DIN Socket
J7: 2x6 Header; PinHeader_2x06_P2.54mm_Vertical
J8: 2x3 Header; PinHeader_2x03_P2.54mm_Vertical
J9: 3.5mm TRS Jack; Jack_3.5mm_CUI_SJ1-3533NG_Horizontal
J10: 1x3 Header; PinHeader_1x03_P2.54mm_Vertical
J12, J13: Mini-DIN-6; mini-DIN 6
J14: DB25_Female; DSUB-25_Male_Horizontal_P2.77x2.84mm_EdgePinOffset7.70mm_Ho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
J15: DE15HD; DSUB-15-HD_Female_Horizontal_P2.29x1.98mm_EdgePinOffset8.35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
J16: Micro_SD_Card_Det; microSD_HC_Hirose_DM3D-SF
J17: DNF; PinHeader_1x07_P2.54mm_Vertical
R1, R3: 470; R_Axial_DIN0204_L3.6mm_D1.6mm_P5.08mm_Horizontal
R2: 10K; R_Axial_DIN0204_L3.6mm_D1.6mm_P5.08mm_Horizontal
R4, R5: 4.7k; R_Axial_DIN0204_L3.6mm_D1.6mm_P5.08mm_Horizontal
R6, R7, R8, R9, R10: 220; R_Axial_DIN0204_L3.6mm_D1.6mm_P5.08mm_Horizontal
R11, R12: 270; R_Axial_DIN0204_L3.6mm_D1.6mm_P5.08mm_Horizontal
R13, R14: 150; R_Axial_DIN0204_L3.6mm_D1.6mm_P5.08mm_Horizontal
R15, R16, R17: 330; R_Axial_DIN0204_L3.6mm_D1.6mm_P5.08mm_Horizontal
R18, R19, R20, R21: 47k; R_Axial_DIN0204_L3.6mm_D1.6mm_P5.08mm_Horizontal
U1: 74LS14; DIP-14_W7.62mm
U2: 6N138; DIP-8_W7.62mm
U3: MCP7940N-xP; DIP-8_W7.62mm
U4: TM4C123G_Launchpad; Launchpad_4x10
U5: ATmega48A-PU; DIP-28_W7.62mm
U6: MAX3232; DIP-16_W7.62mm
Y1: 32,768 kHz; Crystal_DS26_D2.0mm_L6.0mm_Horizontal

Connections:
+3V3: C3.1, J7.12, J16.4, J17.5, R1.1, R3.2, R18.1, R19.1, R20.1, R21.1, U3.8, U4.1.1
+5V: C1.1, C2.1, C7.1, C8.1, C14.1, J1.1, J3.2, J8.2, J12.4, J13.4, R4.2, R5.1, R9.1, R10.1, U1.14, U2.8, U4.3.1, U5.7, U5.20, U5.21
+BATT: BT1.1, U3.3
/ACK: J14.10, U5.4
/AUTOF: J14.14, U5.12
/BUSY: J14.11, U5.5
/D0: J14.2, U5.14
/D1: J14.3, U5.15
/D2: J14.4, U5.16
/D3_MOSI: J8.4, J14.5, U5.17
/D4_MISO: J8.1, J14.6, U5.18
/D5_SCK: J8.3, J14.7, U5.19
/D6: J14.8, U5.9
/D7: J14.9, U5.10
/ERROR: J14.15, U5.11
/INIT: J14.16, U1.10
/KB_CLK: J12.5, U5.23
/KB_DATA: J12.1, U5.25
/MS_CLK: J13.5, U5.24
/MS_DATA: J13.1, U5.26
/PA2_SD_CLK: J16.5, J17.4, R19.2, U4.2.10
/PA3_SD_CS: J16.2, J17.7, R21.2, U4.2.9
/PA4_SD_MISO: J16.7, J17.2, R18.2, U4.2.8
/PA5_SD_MOSI: J16.3, J17.6, R20.2, U4.1.8
/PA6_I2C_SCL: J3.4, R4.1, U4.1.9
/PA7_I2C_SDA: J3.3, R5.2, U3.5, U3.6, U4.1.10
/PB0_U1RX: J7.10, U4.1.3
/PB1_U1TX: J7.8, U4.1.4
/PB2_INIT: U1.13, U4.2.2
/PB4_VGA_HSYNC: J15.13, U4.1.7
/PB5_VGA_VSYNC: J15.14, U4.1.2
/PB7_VGA_GRN: R16.2, U4.2.6
/PC4_U1RTS: J7.6, U4.4.4
/PC5_U1CTS: J7.4, U4.4.5
/PC6_MIDI_IN: R1.2, U1.1, U2.6, U4.4.6
/PC7_MIDI_OUT: U1.9, U4.4.7
/PD2_SD_ACT: D1.1, U4.3.5
/PD3_VGA_BLU: R17.2, U4.3.6
/PD6_JS_LEFT: J2.3, U4.4.8
/PD7_JS_RIGHT: J2.4, U4.4.9
/PE: J14.12, U5.6
/PE0_U7RX: U4.2.3, U5.2
/PE1_U7TX: U4.3.7, U5.3
/PE2_JS_UP: J2.1, U4.3.8
/PE3_JS_DOWN: J2.2, U4.3.9
/PE4_AUDIO_L: R11.1, U4.1.5
/PE5_AUDIO_R: R12.1, U4.1.6
/PF1_VGA_RED: R15.2, U4.3.10
/PF4_JS_FIRE: J2.6, U4.4.10
/RS232_CTS: J11.8, U6.8
/RS232_RTS: J11.7, U6.7
/RS232_RX: J11.2, U6.13
/RS232_TX: J11.3, U6.14
/SEL: J14.13, U5.28
/SELPRIN: J14.17, U5.27
/STROBE: J14.1, U5.13
GND: BT1.2, C1.2, C2.2, C3.2, C4.1, C5.1, C7.2, C8.2, C9.2, C10.2, C13.1, C14.2, C17.2, J1.2, J2.8, J3.1, J4.2, J6.2, J7.1, J7.2, J8.6, J9.S, J11.5, J12.3, J13.3, J14.18, J14.19, J14.20, J14.21, J14.22, J14.23, J14.24, J14.25, J15.0, J15.5, J15.6, J15.7, J15.8, J16.6, J16.11, J17.3, R2.2, R13.2, R14.2, U1.7, U2.5, U3.4, U4.2.1, U4.3.2, U5.8, U5.22, U6.15
unnamed: C4.2, U3.1, Y1.1
unnamed: C5.2, U3.2, Y1.2
unnamed: C6.1, U6.1
unnamed: C6.2, U6.3
unnamed: C10.1, C16.1, R12.2, R14.1
unnamed: C11.1, U6.4
unnamed: C11.2, U6.5
unnamed: C12.1, C17.1, J7.11, U6.16
unnamed: C12.2, U6.2
unnamed: C13.2, U6.6
unnamed: C9.1, C15.1, R11.2, R13.1
unnamed: C15.2, J9.R, J10.1
unnamed: C16.2, J10.3
unnamed: D1.2, R3.1
unnamed: D2.1, J5.5, U2.2
unnamed: D2.2, R8.1, U2.3
unnamed: J4.4, R9.2
unnamed: J4.5, R6.2
unnamed: J5.4, R8.2
unnamed: J6.4, R10.2
unnamed: J6.5, R7.2
unnamed: J7.3, U6.9
unnamed: J7.5, U6.10
unnamed: J7.7, U6.11
unnamed: J7.9, U6.12
unnamed: J8.5, U5.1
unnamed: J9.T, J10.2
unnamed: J15.1, R15.1
unnamed: J15.2, R16.1
unnamed: J15.3, R17.1
unnamed: R2.1, U2.7
unnamed: R6.1, U1.6
unnamed: R7.1, U1.4
unnamed: U1.2, U1.5
unnamed: U1.3, U1.8
unnamed: U1.11, U1.12

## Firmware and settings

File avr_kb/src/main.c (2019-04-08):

/** @file main.c
 *
 * I/O Controller Firmware for Monotron. Implements an SPP LPT port, and a
 * PS/2 keyboard and mouse port.
 *
 * | Port   | Pin |  Direction     | Name          | Routed to  | Description              |
 * |--------|-----|----------------|------------- -|------------|--------------------------|
 * | B      | 0   | Output         | LPT_D0        | J13 pin 2  | LPT Output bit 0         |
 * | B      | 1   | Output         | LPT_D1        | J13 pin 3  | LPT Output bit 1         |
 * | B      | 2   | Output         | LPT_D2        | J13 pin 4  | LPT Output bit 2         |
 * | B      | 3   | Output         | LPT_D3        | J13 pin 5  | LPT Output bit 3         |
 * | B      | 4   | Output         | LPT_D4        | J13 pin 6  | LPT Output bit 4         |
 * | B      | 5   | Output         | LPT_D5        | J13 pin 7  | LPT Output bit 5         |
 * | B      | 6   | Output         | LPT_D6        | J13 pin 8  | LPT Output bit 6         |
 * | B      | 7   | Output         | LPT_D7        | J13 pin 9  | LPT Output bit 7         |
 * | C      | 0   | I/O Open-drain | KB_CLK        | J14 pin 5  | PS/2 Keyboard clock      |
 * | C      | 1   | I/O Open-drain | MS_CLK        | J15 pin 5  | PS/2 Mouse clock         |
 * | C      | 2   | I/O Open-drain | KB_DATA       | J14 pin 1  | PS/2 Keyboard data       |
 * | C      | 3   | I/O Open-drain | MS_DATA       | J15 pin 1  | PS/2 Mouse data          |
 * | C      | 4   | Output         | LPT_nINIT     | J13 pin 16 | Initialise Printer       |
 * | C      | 5   | Input          | LPT_SEL       | J13 pin 13 | Select (from printer)    |
 * | C      | 6   | Output         | LPT_nSELPRIN  | J13 pin 17 | Select (to printer)      |
 * | D      | 0   | Input          | UART_RX       | U1 PE1     | UART receive from MCU    |
 * | D      | 1   | Output         | UART_TX       | U1 PE0     | UART transmit to MCU     |
 * | D      | 2   | Input          | LPT_nACK      | J13 pin 10 | Acknowledge from Printer |
 * | D      | 3   | Input          | LPT_BUSY      | J13 pin 11 | Printer is Busy          |
 * | D      | 4   | Input          | LPT_nPE       | J13 pin 12 | Printer found Paper End  |
 * | D      | 5   | Input          | LPT_nERROR    | J13 pin 15 | Printer Error            |
 * | D      | 6   | Output         | LPT_nAUTOFEED | J13 pin 14 | Enable Auto Feed         |
 * | D      | 7   | Output         | LPT_nSTROBE   | J13 pin 1  | Latch data               |
 *
 * @author Jonathan Pallant <github@thejpster.org.uk>
 * @copyright 2019 Jonathan Pallant
 * @licence MIT or Apache 2.0 at your option.
 */

/**************************************************
* Includes
***************************************************/

#include <inttypes.h>
#include <stdbool.h>

#ifdef __AVR__
#include <avr/interrupt.h>
#include <avr/io.h>
#include <avr/sleep.h>
#include <avr/wdt.h>
#include <avr-uart/uart.h>
#else
#define _BV(bit) (1 << (bit))
#include <stdio.h>
#include <stdlib.h>
#include "fake_uart.h"
#endif
#include "keypress.h"
#include "keycodes.h"
#include "protocol.h"

/**************************************************
* Defines
***************************************************/

// Port B
#define PB_LPT_D0 _BV(0)
#define PB_LPT_D1 _BV(1)
#define PB_LPT_D2 _BV(2)
#define PB_LPT_D3 _BV(3)
#define PB_LPT_D4 _BV(4)
#define PB_LPT_D5 _BV(5)
#define PB_LPT_D6 _BV(6)
#define PB_LPT_D7 _BV(7)

// Port C
#define PC_KB_CLK _BV(0)
#define PC_MS_CLK _BV(1)
#define PC_KB_DATA _BV(2)
#define PC_MS_DATA _BV(3)
#define PC_LPT_nINIT _BV(4)
#define PC_LPT_SEL _BV(5)
/**
 * This clashes with Reset. On some chips the RSTDISBL fuse isn't set and so
 * this pin won't function as a GPIO - the printer side should therefore be
 * tied low in hardware so the printer is always selected. Where RSTDISBL is
 * set, this pin can be connected to the printer, but you can re-program the
 * chip with an ISP.
*/
#define PC_LPT_nSELPRIN _BV(6)

// Port D
#define PD_UART_RX _BV(0)
#define PD_UART_TX _BV(1)
#define PD_LPT_nACK _BV(2)
#define PD_LPT_BUSY _BV(3)
#define PD_LPT_nPE _BV(4)
#define PD_LPT_nERROR _BV(5)
#define PD_LPT_nAUTOFEED _BV(6)
#define PD_LPT_nSTROBE _BV(7)

#define OUR_UART_BAUD 115200UL

#define SHIFT_REGISTER_INIT_WORD _BV(0)
#define SHIFT_REGISTER_COMPLETE_MASK _BV(12)

#define EXTENDED_KEY_CODE 0xE0
#define RELEASE_KEY_CODE 0xF0

#define MOUSE_BITS_OVERFLOW_Y _BV(7)
#define MOUSE_BITS_OVERFLOW_X _BV(6)
#define MOUSE_BITS_SIGN_Y _BV(5)
#define MOUSE_BITS_SIGN_X _BV(4)
#define MOUSE_BITS_1_BIT _BV(3)
#define MOUSE_BITS_MIDDLE_BUTTON _BV(2)
#define MOUSE_BITS_RIGHT_BUTTON _BV(1)
#define MOUSE_BITS_LEFT_BUTTON _BV(0)

#define LPT_BUFFER_SIZE 32

/** Same as the TM4C123 */
#define UART_RX_BUFFER_SIZE 16

/** Same as the TM4C123 */
#define UART_TX_BUFFER_SIZE 16

#define VERSION 0

#ifdef __AVR__
#define soft_reset()           \
    do {                       \
        wdt_enable(WDTO_15MS); \
        for (;;) {             \
        }                      \
    } while (0)
#define run() 1
#else
static uint8_t should_run = 1;
#define soft_reset() do { should_run = 0; } while(0)
#define run() should_run
#define sleep_mode() do { } while(0)
#endif

/**************************************************
* Data Types
**************************************************/

typedef struct fifo_t {
    volatile uint8_t* p_data;
    uint8_t size;
    volatile uint8_t head;
    volatile uint8_t tail;
    volatile uint8_t dropped_bytes;
} fifo_t;

typedef enum bit_state_t {
    BIT_STATE_LOW,
    BIT_STATE_HIGH,
    BIT_STATE_WAITING
} bit_state_t;

typedef enum keyboard_state_t {
    KEYBOARD_STATE_IDLE,
    KEYBOARD_STATE_EXTENDED,
    KEYBOARD_STATE_EXTENDED_RELEASE,
    KEYBOARD_STATE_RELEASE
} keyboard_state_t;

/**************************************************
* Function Prototypes
**************************************************/

static void setup_io(void);
static bool process_port_serial(void);
static bool process_port_keyboard(void);
static bool process_port_mouse(void);
static bool process_port_parallel(void);
static void process_command(uint8_t byte);
static bool decode_word(uint16_t word, uint8_t* p_output_byte);
static void store_keyboard_byte(bool is_keydown, uint8_t byte);
static void store_keyboard_extended_byte(bool is_keydown, uint8_t byte);
static void store_keyevent(uint8_t byte);
static void send_reset_cfm(void);
static void send_ps2_data_cfm(uint8_t kb0, uint8_t kb1, uint8_t kb2, uint8_t mouse_status, uint8_t mouse_x, uint8_t mouse_y);
static void send_ps2_led_cfm(void);
static void send_lpt_data_cfm(void);
static void send_lpt_read_cfm(void);
static void send_lpt_ctrl_cfm(void);
static void send_lpt_buffered_data_cfm(uint8_t status);
static void send_lpt_read_pend_cfm(void);
static void send_lpt_set_mode_cfm(void);
static void send_ping_cfm(void);
static void send_bootloader_cfm(void);
static void send_booted_ind(bool keyboard, bool mouse, uint8_t version);
static void send_ps2_data_ind(void);
static void send_lpt_buffer_empty_ind(void);
static void send_lpt_read_pend_ind(uint8_t pins);
static void send_bad_command_ind(void);

#ifdef __AVR__
void wdt_init(void) __attribute__((naked)) __attribute__((section(".init3")));
#endif

/**************************************************
* Public Data
**************************************************/

/* None */

/**************************************************
* Private Data
**************************************************/

/**
 * PS/2 data is clocked in as 13-bits into this 16-bit register. We default
 * with a 1 bit in the LSB. When this 1 bit has been shifted up to the 13-bit
 * we know we've clocked in a full word.
 */
static uint16_t g_keyboard_word;

/**
 * PS/2 data is clocked in as 13-bits into this 16-bit register. We default
 * with a 1 bit in the LSB. When this 1 bit has been shifted up to the 13-bit
 * we know we've clocked in a full word.
 */
static uint16_t g_mouse_word;

/**
 * Records the number of units the mouse has moved in the X direction since we
 * were last asked for the mouse position.
 */
static int16_t g_mouse_x = 0;

/**
 * Records the number of units the mouse has moved in the Y direction since we
 * were last asked for the mouse position.
 */
static int16_t g_mouse_y = 0;

/**
 * Records the mouse button status and overflow bits. See the MOUSE_BITS_xxx
 * macros.
 */
static uint8_t g_mouse_bits = 0;

/**
 * Buffers up to three keypress event bytes. A value of 0x00 means (no
 * keypress).
 */
static uint8_t g_keyboard_data[3] = { 0 };

/**
 * Tracks the keyboard state.
 */
static keyboard_state_t g_keyboard_state = KEYBOARD_STATE_IDLE;

/**
 * How many command bytes we're waiting for.
 */
static uint8_t g_command_bytes = 0;

/**
 * A buffer of bytes for the LPT to emit autonomously.
 */
volatile static uint8_t g_lpt_buffer[LPT_BUFFER_SIZE] = { 0 };
static fifo_t g_lpt_fifo = { 0 };

/**
 * The previous value of the PS/2 pins in port C, so we
 * can tell what changed when the interrupt fires.
 */
static volatile uint8_t g_pc_previous = 0;

/**
 * The last PS/2 mouse bit received.
 */
static volatile bit_state_t g_ms_bit = BIT_STATE_WAITING;

/**
 * The last PS/2 keyboard bit received.
 */
static volatile bit_state_t g_kb_bit = BIT_STATE_WAITING;


/**************************************************
* Public Functions
***************************************************/

/**
 * Entry point to our program.
 *
 * @return Never returns on AVR. Return on RESET_REQ on Linux.
 */
int main(void)
{
    g_lpt_fifo.p_data = g_lpt_buffer;
    g_lpt_fifo.size = sizeof(g_lpt_buffer);
    g_keyboard_word = SHIFT_REGISTER_INIT_WORD;
    g_mouse_word = SHIFT_REGISTER_INIT_WORD;
    DDRB = 0xFF;
    PORTB = 0xAA;
    volatile uint8_t test = 0;
    for(;;) {
        test++;
    }

    // setup_io();
    // bool mouse = false;
    // bool keyboard = false;
    // // Scan for keyboard and mouse here
    // // TODO
    // // Send booted ind
    // send_booted_ind(keyboard, mouse, VERSION);
    // uart_flush();
    // // Wait for commands. We handle keyboard, mouse and LPT ack under
    // // interrupt.
    // uint8_t leds = 0;
    // uint16_t counter = 0;
    // while(run()) {
    //     if (counter++ == 0) {
    //         PORTB = ++leds;
    //     }
    //     bool more_processing = false;
    //     do {
    //         more_processing |= process_port_keyboard();
    //         more_processing |= process_port_mouse();
    //         more_processing |= process_port_parallel();
    //         more_processing |= process_port_serial();
    //     } while(more_processing);
    //     sleep_mode();
    // }
}

/**
 * Pin-change interrupt for Port C.
 */
ISR(PCINT1_vect)
{
    uint8_t pins = PINC & (PC_KB_CLK | PC_KB_DATA | PC_MS_CLK | PC_MS_DATA);
    uint8_t changed = g_pc_previous ^ pins;
    if ((changed & PC_KB_CLK) && ((pins & PC_KB_CLK) == 0)) {
        // Falling edge on KB_CLK
        g_kb_bit = (pins & PC_KB_DATA);
    }
    if ((changed & PC_MS_CLK) && ((pins & PC_MS_CLK) == 0)) {
        // Falling edge on MS_CLK
        g_ms_bit = (pins & PC_MS_DATA);
    }
    g_pc_previous = pins; // Save the previous state so you can tell what changed
}

// #ifdef __AVR__
// /**
//  * UART0 receive interrupt service routine. Copies byte from UART data
//  * register to FIFO. If FIFO is full, byte is dropped.
//  */
// ISR( USART_RX_vect )
// {
//     uint8_t head = uart_rx_fifo.head;
//     uint8_t tail = uart_rx_fifo.tail;
//     head = head + 1;
//     if (head == uart_rx_fifo.size) {
//         head = 0;
//     }
//     if (head == tail) {
//         // FIFO is full, so we drop the byte and increment a counter
//         uart_rx_fifo.dropped_bytes++;
//     } else {
//         uart_rx_fifo.p_data[head] = UDR0;
//         uart_rx_fifo.head = head;
//     }
// }
// #endif

/**************************************************
* Private Functions
***************************************************/

/**
 * Configure the I/O pins correctly.
 */
static void setup_io(void)
{
#ifdef __AVR__
    // 1 = output, 0 = input
    DDRB = 0xFF; // All outputs
    DDRC = PC_LPT_nINIT | PC_LPT_nSELPRIN;
    DDRD = PD_UART_TX | PD_LPT_nAUTOFEED | PD_LPT_nSTROBE;
    PORTB = 0xFF; // Outputs high by default
    PORTC = PC_LPT_nINIT | PC_LPT_nSELPRIN;
    PORTD = PD_LPT_nSTROBE | PD_LPT_nAUTOFEED;
#endif

    // Configure interrupts here.
    // We need to interrupt on LPT_nACK and UART.

    uart_init(UART_BAUD_SELECT(OUR_UART_BAUD, F_CPU));
}

/**
 * Handle the Serial port.
 * @return true if more processing required, false if safe to sleep.
 */
static bool process_port_serial(void)
{
    bool result = true;
    uint16_t status = uart_getc();
    uint8_t data = status & 0x00FF;
    switch (status & 0xFF00) {
    case UART_NO_DATA:
        result = false;
        break;
    case 0:
        // Process received data
        process_command(data);
        break;
    case UART_BUFFER_OVERFLOW:
    case UART_OVERRUN_ERROR:
    case UART_FRAME_ERROR:
        // Uh-oh. Better reboot.
        soft_reset();
        break;
    default:
        soft_reset();
        break;
    }
    return result;
}

/**
 * Handle the Keyboard port.
 * @return true if more processing required, false if safe to sleep.
 */
static bool process_port_keyboard(void)
{
    bit_state_t state = g_kb_bit;
    if (state != BIT_STATE_WAITING) {
        uint16_t word = g_keyboard_word;
        word <<= 1;
        if (state == BIT_STATE_HIGH) {
            word |= 1;
        } else {
            word <<= 1;
        }
        if (word & SHIFT_REGISTER_COMPLETE_MASK) {
            uint8_t data = 0;
            if (decode_word(word, &data)) {
                word = SHIFT_REGISTER_INIT_WORD;
                switch (g_keyboard_state) {
                    case KEYBOARD_STATE_IDLE:
                    {
                        switch (data) {
                            case EXTENDED_KEY_CODE:
                                g_keyboard_state = KEYBOARD_STATE_EXTENDED;
                                break;
                            case RELEASE_KEY_CODE:
                                g_keyboard_state = KEYBOARD_STATE_RELEASE;
                                break;
                            default:
                                store_keyboard_byte(false, data);
                                break;
                        }
                    }
                    break;
                    case KEYBOARD_STATE_EXTENDED:
                    {
                        store_keyboard_extended_byte(false, data);
                    }
                    break;
                    case KEYBOARD_STATE_EXTENDED_RELEASE:
                    {
                        store_keyboard_extended_byte(true, data);
                    }
                    break;
                    case KEYBOARD_STATE_RELEASE:
                    {
                        switch (data) {
                            case EXTENDED_KEY_CODE:
                                g_keyboard_state = KEYBOARD_STATE_EXTENDED;
                                break;
                            default:
                                store_keyboard_byte(true, data);
                                break;
                        }
                    }
                    break;
                }
            }
        }
        g_keyboard_word = word;
    }
    return false;
}

/**
 * Handle the Mouse port.
 * @return true if more processing required, false if safe to sleep.
 */
static bool process_port_mouse(void)
{
    return false;
}

/**
 * Handle the Parallel port.
 * @return true if more processing required, false if safe to sleep.
 */
static bool process_port_parallel(void)
{
    return false;
}


/**
 * Process a byte from the MCU.
 */
static void process_command(uint8_t byte)
{
    if (g_command_bytes == 0) {
        // It's a new command
        switch (byte) {
        case PROTOCOL_RESET_REQ:
            send_reset_cfm();
            uart_flush();
            soft_reset();
            break;
        case PROTOCOL_PS2_DATA_REQ: {
            uint8_t kb0 = g_keyboard_data[0];
            uint8_t kb1 = g_keyboard_data[1];
            uint8_t kb2 = g_keyboard_data[2];
            uint8_t st = g_mouse_bits;
            uint8_t mx = 0;
            uint8_t my = 0;
            if ((g_mouse_x > 255) || (g_mouse_x < -255)) {
                st |= MOUSE_BITS_OVERFLOW_X;
                mx = 255;
            } else {
                mx = g_mouse_x > 0 ? g_mouse_x : -g_mouse_x;
            }
            st |= g_mouse_x > 0 ? 0 : MOUSE_BITS_SIGN_X;
            if ((g_mouse_y > 255) || (g_mouse_y < -255)) {
                st |= MOUSE_BITS_OVERFLOW_Y;
                my = 255;
            } else {
                my = g_mouse_y > 0 ? g_mouse_y : -g_mouse_y;
            }
            st |= g_mouse_y > 0 ? 0 : MOUSE_BITS_SIGN_Y;
            send_ps2_data_cfm(kb0, kb1, kb2, st, mx, my);
        } break;
        case PROTOCOL_PS2_LED_REQ:
            // send_ps2_led_cfm();
            // Command unsupported
            send_bad_command_ind();
            break;
        case PROTOCOL_LPT_DATA_REQ:
            // send_lpt_data_cfm();
            // Command unsupported
            send_bad_command_ind();
            break;
        case PROTOCOL_LPT_READ_REQ:
            // send_lpt_read_cfm();
            // Command unsupported
            send_bad_command_ind();
            break;
        case PROTOCOL_LPT_CTRL_REQ:
            // send_lpt_ctrl_cfm();
            // Command unsupported
            send_bad_command_ind();
            break;
        case PROTOCOL_LPT_BUFFERED_DATA_REQ:
            // send_lpt_buffered_data_cfm();
            // Command unsupported
            send_bad_command_ind();
            break;
        case PROTOCOL_LPT_READ_PEND_REQ:
            // send_lpt_read_pend_cfm();
            // Command unsupported
            send_bad_command_ind();
            break;
        case PROTOCOL_LPT_SET_MODE_REQ:
            // send_lpt_set_mode_cfm();
            // Command unsupported
            send_bad_command_ind();
            break;
        case PROTOCOL_PING_REQ:
            send_ping_cfm();
            break;
        case PROTOCOL_BOOTLOADER_REQ:
            // send_bootloader_cfm();
            // Command unsupported
            send_bad_command_ind();
            break;
        default:
            send_bad_command_ind();
            break;
        }
    }
}

/**
 * Convert a 11-bit word (start, 8-data bits, parity, stop) to an 8-bit byte.
 *
 * @return true if word OK, false otherwise
 */
static bool decode_word(uint16_t word, uint8_t* p_output_byte) {
    // Stop bit
    if ((word & _BV(10)) == 0) {
        return false;
    }
    // Start bit
    if ((word & _BV(0)) != 0) {
        return false;
    }
    // TODO check parity _BV(9) here!
    *p_output_byte = (uint8_t) ((word >> 1) & 0xFF);
    return true;
}

/**
 * Handle a scan-code set 2 keyboard byte, storing it in the key event buffer.
 */
static void store_keyboard_byte(bool is_keydown, uint8_t byte) {
    uint8_t up_down_bit = is_keydown ? KEYPRESS_KEYDOWN : KEYPRESS_KEYUP;
    if (byte <= KEYCODE_SCS2_SCROLLLOCK) {
        // As a short-cut, these scan-code 2 code map straight through
        store_keyevent(byte | up_down_bit);
    } else if (byte == KEYCODE_SCS2_F7) {
        // This is the only one that doesn't
        store_keyevent(KEYPRESS_F7 | up_down_bit);
    }
}

/**
 * Handle a extended scan-code set 2 keyboard byte, storing it in the key
 * event buffer.
 */
static void store_keyboard_extended_byte(bool is_keydown, uint8_t byte) {
    uint8_t up_down_bit = is_keydown ? KEYPRESS_KEYDOWN : KEYPRESS_KEYUP;
    uint8_t data = 0;
    switch (byte) {
    case KEYCODE_SCS2_EXTENDED_ALTRIGHT:
        data = KEYPRESS_ALTRIGHT;
        break;
    case KEYCODE_SCS2_EXTENDED_CONTROLRIGHT:
        data = KEYPRESS_CONTROLRIGHT;
        break;
    case KEYCODE_SCS2_EXTENDED_WINDOWSLEFT:
        data = KEYPRESS_WINDOWSLEFT;
        break;
    case KEYCODE_SCS2_EXTENDED_WINDOWSRIGHT:
        data = KEYPRESS_WINDOWSRIGHT;
        break;
    case KEYCODE_SCS2_EXTENDED_MENUS:
        data = KEYPRESS_MENUS;
        break;
    case KEYCODE_SCS2_EXTENDED_NUMPADSLASH:
        data = KEYPRESS_NUMPADSLASH;
        break;
    case KEYCODE_SCS2_EXTENDED_NUMPADENTER:
        data = KEYPRESS_NUMPADENTER;
        break;
    case KEYCODE_SCS2_EXTENDED_END:
        data = KEYPRESS_END;
        break;
    case KEYCODE_SCS2_EXTENDED_ARROWLEFT:
        data = KEYPRESS_ARROWLEFT;
        break;
    case KEYCODE_SCS2_EXTENDED_HOME:
        data = KEYPRESS_HOME;
        break;
    case KEYCODE_SCS2_EXTENDED_INSERT:
        data = KEYPRESS_INSERT;
        break;
    case KEYCODE_SCS2_EXTENDED_DELETE:
        data = KEYPRESS_DELETE;
        break;
    case KEYCODE_SCS2_EXTENDED_ARROWDOWN:
        data = KEYPRESS_ARROWDOWN;
        break;
    case KEYCODE_SCS2_EXTENDED_ARROWRIGHT:
        data = KEYPRESS_ARROWRIGHT;
        break;
    case KEYCODE_SCS2_EXTENDED_ARROWUP:
        data = KEYPRESS_ARROWUP;
        break;
    case KEYCODE_SCS2_EXTENDED_PAGEDOWN:
        data = KEYPRESS_PAGEDOWN;
        break;
    case KEYCODE_SCS2_EXTENDED_PAGEUP:
        data = KEYPRESS_PAGEUP;
        break;
    default:
        break;
    }
    if (data != 0) {
        store_keyevent(data | up_down_bit);
    }
}

/**
 * Buffer a key event for delivery.
 */
static void store_keyevent(uint8_t byte) {
    if (g_keyboard_data[0] == 0) {
        g_keyboard_data[0] = byte;
    } else if (g_keyboard_data[1] == 0) {
        g_keyboard_data[1] = byte;
    } else if (g_keyboard_data[2] == 0) {
        g_keyboard_data[2] = byte;
    } else {
        // We dropped a key event. Oops.
    }
}

/**
 * Send a RESET_CFM to the MCU.
 */
static void send_reset_cfm(void)
{
    uart_putc(PROTOCOL_RESET_CFM);
}
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

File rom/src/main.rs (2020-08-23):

//! # Monotron
//!
//! > A simple 1980's home computer style application for the Tiva-C Launchpad
//!
//! See README.md for more details.
//!
//! ## SPI pins
//!
//! This chip has 4 SPI devices. They are on the following pins:
//!
//! 1.02         PB5     SSI2Fss
//! 1.07         PB4     SSI2Clk
//! 1.08         PA5     SSI0Tx
//! 2.04         PF0     SSI1Rx
//! 2.04         PF0     SSI1Rx / User Switch 2
//! 2.06/3.04    PD1/PB7 SSI2Tx / SSI3Fss / SSI1Fss
//! 2.07/3.03    PB6/PD0 SSI2Rx / SSI3Clk / SSI1Clk
//! 2.08         PA4     SSI0Rx
//! 2.09         PA3     SSI0Fss
//! 2.10         PA2     SSI0Clk
//! 3.05         PD2     SSI3Rx / SSI1Rx
//! 3.06         PD3     SSI3Tx / SSI1Tx
//! 3.10         PF1     SSI1Tx
//! 4.02         PF3     SSI1Fss
//!
//! Note that there are 0-ohm links between 2.07 and 3.03 and between 2.06 and
//! 3.04 for MSP430 compatibility reasons. This limits the pins we can use for
//! SPI.
//!
//! We use:
//! * SSI1Tx for Red on PF1 / 3.10
//! * SSI2Tx for Green on PB7 / 3.04=2.06
//! * SSI3Tx for Blue on PD3 / 3.06
//! * Timer1 Channel A PB4 is H-Sync
//! * GPIO PB5 is V-Sync
//! * M0PWM4 for Audio on PE4 / 1.05.
//! * PC6/PC7/PD6/PD7/PF4 for an Atari 9-pin Joystick.
//! * SSI0 (PA2/PA3/PA4/PA5) for an SD/MMC Interface
//!
//! Reserved for future use:
//! * SSI0, for interfacing with an SD/MMC card.
//! * PB0/PB1/PC4/PC5 for a 5-wire 3.3v UART.
//! * PB2/PE0 for PS/2 +CLK and +DATA.

#![no_main]
#![no_std]
#![allow(deprecated)]
#![feature(llvm_asm)]

// ===========================================================================
// Sub-modules
// ===========================================================================

mod api;
mod ui;

// ===========================================================================
// Imports
// ===========================================================================

extern crate panic_halt;

use cortex_m_rt::{entry, exception};
use fb::AsciiConsole;
use monotron_synth::*;
use tm4c123x_hal as hal;
use vga_framebuffer as fb;

use self::cpu::{interrupt, Interrupt};
use self::hal::bb;
use self::hal::i2c::I2c;
use self::hal::prelude::*;
use self::hal::serial::{NewlineMode, Serial};
use self::hal::sysctl;
use self::hal::tm4c123x as cpu;
use mcp794xx::{Datelike, Timelike};

// ===========================================================================
// Types
// ===========================================================================

/// Holds a `TimeContextInner` in a mutex.
pub struct TimeContext {
    inner: spin::Mutex<TimeContextInner>,
}

/// Holds all of the system peripheral objects and state.
pub struct Context {
    /// The UART connected to the USB-CDC virtual COM port function on the on-board debugger.
    usb_uart: hal::serial::Serial<
        hal::serial::UART0,
        hal::gpio::gpioa::PA1<hal::gpio::AlternateFunction<hal::gpio::AF1, hal::gpio::PushPull>>,
        hal::gpio::gpioa::PA0<hal::gpio::AlternateFunction<hal::gpio::AF1, hal::gpio::PushPull>>,
        (),
        (),
    >,
    /// The UART connected to the keyboard / mouse controller chip.
    keyboard_mouse_uart: hal::serial::Serial<
        hal::serial::UART7,
        hal::gpio::gpioe::PE1<hal::gpio::AlternateFunction<hal::gpio::AF1, hal::gpio::PushPull>>,
        hal::gpio::gpioe::PE0<hal::gpio::AlternateFunction<hal::gpio::AF1, hal::gpio::PushPull>>,
        (),
        (),
    >,
    /// The UART connected to the MIDI interface.
    /// * UART Transmit -> MIDI Out
    /// * MIDI In -> UART Receive + MIDI Through
    midi_uart: hal::serial::Serial<
        hal::serial::UART3,
        hal::gpio::gpioc::PC7<hal::gpio::AlternateFunction<hal::gpio::AF1, hal::gpio::PushPull>>,
        hal::gpio::gpioc::PC6<hal::gpio::AlternateFunction<hal::gpio::AF1, hal::gpio::PushPull>>,
        (),
        (),
    >,
    /// The UART connected to the RS-232 level shifter
    rs232_uart: hal::serial::Serial<
        hal::serial::UART1,
        hal::gpio::gpiob::PB1<hal::gpio::AlternateFunction<hal::gpio::AF1, hal::gpio::PushPull>>,
        hal::gpio::gpiob::PB0<hal::gpio::AlternateFunction<hal::gpio::AF1, hal::gpio::PushPull>>,
        hal::gpio::gpioc::PC4<hal::gpio::AlternateFunction<hal::gpio::AF8, hal::gpio::PushPull>>,
        hal::gpio::gpioc::PC5<hal::gpio::AlternateFunction<hal::gpio::AF8, hal::gpio::PushPull>>,
    >,
    /// Processes scan-codes into key events
    keyboard: pc_keyboard::Keyboard<pc_keyboard::layouts::Uk105Key, pc_keyboard::ScancodeSet2>,
    /// Our I2C bus.
    i2c_bus: I2c<
        cpu::I2C1,
        (
            hal::gpio::gpioa::PA6<
                hal::gpio::AlternateFunction<hal::gpio::AF3, hal::gpio::PushPull>,
            >,
            hal::gpio::gpioa::PA7<
                hal::gpio::AlternateFunction<
                    hal::gpio::AF3,
                    hal::gpio::OpenDrain<hal::gpio::Floating>,
                >,
            >,
        ),
    >,
    /// A single item buffer so that we can 'peek' at the input stream.
    buffered_char: Option<Input>,
    /// Our joystick interface
    joystick: Joystick,
    /// Our SD card controller
    cont: embedded_sdmmc::Controller<
        embedded_sdmmc::SdMmcSpi<
            hal::spi::Spi<
                cpu::SSI0,
                (
                    hal::gpio::gpioa::PA2<
                        hal::gpio::AlternateFunction<hal::gpio::AF2, hal::gpio::PushPull>,
                    >,
                    hal::gpio::gpioa::PA4<
                        hal::gpio::AlternateFunction<hal::gpio::AF2, hal::gpio::PushPull>,
                    >,
                    hal::gpio::gpioa::PA5<
                        hal::gpio::AlternateFunction<hal::gpio::AF2, hal::gpio::PushPull>,
                    >,
                ),
            >,
            hal::gpio::gpioa::PA3<hal::gpio::Output<hal::gpio::PushPull>>,
        >,
        &'static TimeContext,
    >,
    /// Information about the clock speeds we have configured
    clocks: hal::sysctl::Clocks,
    /// If `false`, input errors are squashed (in case we reboot in the middle
    /// of a message from the keyboard controller). Set to `true` when a valid
    /// message has been received.
    seen_keypress: bool,
}

/// Describes the current position of the joystick.
#[derive(Copy, Clone, Debug)]
pub struct JoystickState(u8);

/// Used by our menu runner.
pub struct MenuContext;

/// Tracks the most recent date/time stamp, and the frame count at which we
/// calculated that date/time stamp. Whenever we ask for the time, we move the
/// date/time stamp forwards based on how many frames had elapsed since we
/// last asked.
struct TimeContextInner {
    /// The frame count at which `timestamp` was calculated.
    timestamp_frame_count: u32,
    /// The calendar date / time at `timestamp_frame_count`.
    timestamp: monotron_api::Timestamp,
}
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

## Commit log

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2018-03-04 Added test static bitmaps and test animation. Also pre-loads SPI FIFO using new `buffer_pixels` callback.
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2018-04-23 Put a half a UART in the Context, so we can read chars and exit demos.
2018-04-26 Switched to CodePage 850. Alphabet routine shows the whole alphabet.
2018-04-27 Use manually unrolled assembly to synchronise 3 SPI outputs. Now emits colour! Well, white. Colour support is coming.
2018-04-27 Added a clear screen command, and alphabet does a colour wheel. Colour not currently working though - CPU not fast enough.
2018-05-07 Swap delete for backspace.
    [main.rs]
2018-05-08 Set all timing to 20 MHz. Move hardware out of a global - it doesn't need to be. Move SPI setup to video init callback.
    [main.rs]
2018-05-12 Working on keyboard support. Just needs the SPI slave configuring.
2018-05-13 Move to Timer1 to free up PB6 (attached to PD0) for keyboard.
2018-05-13 Use GPIO interrupts for keyboard. Doesn't work - receives garbage, and not reliably.
    [main.rs]
2018-05-19 Avoid some unnecessary casting in the `write_pixels` function to try and speed it up a bit.
    [main.rs]
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2018-05-19 Version bump. Switch to published vga-framebuffer and menu crates.
2018-05-19 Fix the font panel in MonotronPaint.
    [ui.rs]
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2018-06-23 Remove systicks and replace with video lines. This has fewer interrupts to mess up the video.
    [main.rs, ui.rs]
2018-08-22 Dedicate 24 KiB of RAM to applications. Use colour boot logo and print free RAM.
2018-08-30 Fix H-Sync pin in README
    The monotron I have in front of me has H-Sync (pin 13) connected to PB4, and it worked all weekend. The code also says PB4, so unless I'm misunderstanding something, the README is wrong.
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2018-09-22 Swap LM4F120 for TM4C123.
    [main.rs]
2018-09-22 Add pin map.
    [pin map.ods]
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2018-09-29 Build updates: Use lld.ld Update to latest vga-framebuffer.
2018-09-30 Fix the demos. You can't print magic characters. Replaced Escape, CR, NL and Backspace. Removed trick scan-line colour swap - it didn't work with new code.
2018-10-04 Switch to 2018 edition. Also moved demos menu to demo.rs. Also stoped 'alphabet' having matching fg/bg.
2018-10-11 Mark GPIO 1 as input only.
    [pin map.ods]
2018-10-19 Move fire to PF4.
    [pin map.ods]
2018-10-21 Remove APPLICATION_RAM and shrink SRAM to 8 KiB. We then make a slice pointing to the area above that the linker used. This fixes the application load address to 0x2000_2000.
    [main.rs, ui.rs]
2018-10-25 Clean up jitter.
2018-11-16 Fix warnings about not unwrapping writeln().
    [ui.rs]
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2018-11-18 Adding SDMMC support. Board doesn't currently boot.
    [main.rs]
2018-12-15 Speed up disk loading - ish. We really need a DMA-based SPI driver so we can load from SD card while bashing out pixels. Latest embedded-sdmmc can at least load files over 1 cluster in size (like the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
2018-12-23 Switch to published crates, and add SD/MMC pinout to README.
2018-12-27 Updated pin spreadsheet: * Added SDMMC to SSI0 * Removed GPIO pin numbers
    [pin map.ods]
2018-12-29 Added work in progress schematic.
    [monotron.kicad_pcb, monotron.sch, monotron_rs232_level_shifter.sch]
2018-12-30 Added I/O, RS232 and VGA interfaces. Just audio to add.
    [monotron.sch, monotron_ps2.sch, monotron_rs232_level_shifter.sch]
2018-12-31 Changed to use Launchpad instead of bare chip. PS/2 handled by ATTINY24. LPT handled by MCP23017.
    [monotron.sch, monotron_ps2.sch, monotron_rs232_level_shifter.sch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]
2019-01-01 Adding footprints.
    [monotron.sch, monotron_ps2.sch, monotron_rs232_level_shifter.sch]
2019-01-01 Added footprints. Change SD footprint for breakout board. Changed PS2/LPT interface to single AtMega48A. Moved MAX3232 to main sheet. Added I2C header. Started PCB layout.
    [monotron.kicad_pcb, monotron.sch, monotron_ps2.sch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]
2019-01-06 Added MIDI interface.
    [monotron.sch, monotron_ps2.sch, pin map.ods]
2019-01-06 Added mini-DIN-6 (TE 5749180-1) and DIN-5-180 (RS 491-087) footprints.
2019-01-08 Updated footprints.
    [monotron.kicad_pcb, monotron.sch, monotron_ps2.sch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]
2019-01-08 Primary component layout complete.
    [monotron.kicad_pcb, monotron_ps2.sch]
2019-01-08 Fun with routing!
    [monotron.kicad_pcb]
2019-01-08 Moved some pins around to ease the routing.
    [monotron.kicad_pcb, monotron_ps2.sch]
2019-01-10 Shrunk board a little (components can hang off edge). Relabelled parts to generic names.
    [monotron.kicad_pcb, monotron.sch]
2019-01-12 Adjusted component layout again. ) More room between MIDI connectors. ) SD/MMC connector now under Launchpad board
    [monotron.kicad_pcb, monotron.sch, monotron_ps2.sch]
2019-01-12 Rotate SD card to match proto-pic board. Shift Launchpad back so you can get to SD card to eject it. Move I2C header to somewhere you can access it.
    [monotron.kicad_pcb]
2019-01-12 Finished PCB layout.
    [monotron.kicad_pcb, monotron.sch, monotron_ps2.sch]
2019-01-12 Add Gerbers and PDFs.
    [monotron-B.Cu.gbr, monotron-B.Mask.gbr, monotron-B.Paste.gbr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]
2019-01-12 Connect unused inverter inputs to ground.
    [monotron-B.Cu.gbr, monotron-B.Mask.gbr, monotron-B.Paste.gbr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]
2019-01-12 Adjusted UART silk screen labels.
    [monotron-B.Cu.gbr, monotron-B.Mask.gbr, monotron-B.Paste.gbr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]
2019-01-12 Fix split ground-plane. Moved a few bottom tracks to make ground fill larger.
    [monotron-B.Cu.gbr, monotron-B.Mask.gbr, monotron-B.Paste.gbr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]
2019-01-13 Add battery-backed RTC. Move MIDI to sub-sheet.
    [MIDI_IF.sch, monotron.sch, monotron_ps2.sch]
2019-01-14 Finished adding RTC to PCB layout.
    [MIDI_IF.sch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]
2019-01-15 Cleaned up PCB layout a bit.
    [MIDI_IF.sch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]
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2019-01-20 Added AVR-UART library. Taken from https://github.com/andygock/avr-uart @ 6773f42.
2019-01-20 Switch messages to be ASCII characters to ease testing.
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2019-01-20 Return from main on RESET_REQ. Make testing easier.
    [main.c]
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2019-01-24 Readme update (#56)
    * Adding PCB pinouts to README.
    * Added notes on:
    ) the extra UARTs
    ) the PCB
    ) the PS/2 and LPT ports via the AtMega
2019-01-24 Add the three new UARTS. Renamed existing uart to usb_uart.
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2019-01-30 Had problems with crashing - ditch a bunch of stuff and go back to basics. Also realised DDR was backwards.
    [main.c]
2019-02-04 Keyboard input works! Tested with Dell UK PS/2 keyboard. Note, we're just passing raw scan-codes over the UART at the moment, rather than the fancy protocol I invented.
    NB: PS/2 connector must be fitted on reverse of PCB.
    [main.rs]
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2019-02-06 Fix rs232 (#57)
    * Added RS-232 read command
    * Switch to AF8 for the RTS/CTS (AF2 was wrong).
    Needs updated tm4c-hal.
    [main.rs, ui.rs]
2019-02-10 Updated Schematic to 0.8.0. (PCB layout still at 0.7.0). Added BOM.
    [MIDI_IF.sch, bill_of_materials.ods, monotron.sch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]
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2019-02-19 Fix up I2C support. ) SCL must not be open drain on the TM4C123 - magic happens internally in I2C mode to make it effectively open-drain, but also operate at high-speed.
    [main.rs]
2019-02-19 Add commands to read/write from simple register based I2C devices. Tested with MCP7940N RTC.
2019-02-19 Tidied up schematic.
    [MIDI_IF.sch, monotron.kicad_pcb, monotron.sch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]
2019-03-05 WIP re-laying out board.
    [monotron.kicad_pcb, monotron.sch]
2019-04-08 Don't leak dir handle when file open fails.
    [ui.rs]
2019-04-28 Move ISRs into ram. Add second Timer ISR to fix jitter for existing ISR.
    [main.rs]
2019-04-28 Undo changes which move ISRs to RAM. The third interrupt with WFI is enough to stabilise the jitter, even in an application which runs a hard loop.
    [main.rs]
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2019-07-16 Use the new API crate. Moves context into a static. This removes the need for the monotron-apps crate to maintain a static. It also allows us to implement println!
2019-07-16 Implement gettime (with a fixed value).
    [api.rs]
2019-08-14 RTC get/set support, and 'flip' command. Flip is a Work in Progress.
    [main.rs, ui.rs]
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2019-08-15 Fix up flip routine.
    [ui.rs]
2019-08-17 Fix docs for get_cursor.
    [api.rs]
2019-08-21 Fix duplicate Handle type.
    Yes, even simple changes need testing.
    [api.rs]
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2020-08-05 Fix build errors due to changes in RTC/Rust
    [main.rs, ui.rs]

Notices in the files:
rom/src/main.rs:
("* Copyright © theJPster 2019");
